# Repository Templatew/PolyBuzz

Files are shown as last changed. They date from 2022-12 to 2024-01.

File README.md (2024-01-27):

# Polybuzz

## Overview

Polybuzz is an innovative and interactive game box developed as a school project. It combines the excitement of arcade games with reflex testing exercises similar to those used in F1 pilot training. This versatile device offers multiple game modes and features a reward system that dispenses a treat after each game.

## Features

- **Multiple Game Modes:** Choose your game mode and play duration using a rotary encoder and an LCD screen.
- **Reward System:** Earn treats dispensed into a tray after each game.
- **Customizable Gameplay:** Adjust game settings for a personalized experience.

## Hardware Requirements

- Arduino Mega
- Rotary encoder
- LCD screen
- Various buttons and LEDs
- Power supply and other electrical components

## Installation

1. Assemble the hardware components based on the electrical schematic provided.
2. Upload the provided code to the Arduino Mega.

## How to Play

- Turn the rotary encoder to scroll through game modes.
- Press the encoder to select a mode and, if required, set the game duration.
- Engage in reflex-based games or other arcade-style challenges.
- Collect your reward after each game.

## Future Enhancements

- Addition of more game modes and difficulty levels.
- Integration of a score-saving feature using an SD card.

## Contributors

 - [CAZAUBON Lorenz](https://github.com/Templatew)
 - [MAUVOISIN Paul](https://github.com/Poblit0)

## Gallery
a4a9868a-1191-4484-97f6-19bce6ff1df2

https://github.com/Templatew/PolyBuzz/assets/96289463/65af232c-c642-4c31-b5ea-772e865da6ab

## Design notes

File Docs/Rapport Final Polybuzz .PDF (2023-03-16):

CAZAUBON Lorenz
MAUVOISIN Paul
G1 | PEIP2 | POLYBUZZ

### Sommaire

### - Présentation (page 2)

### - Planning (page 3)

### - Schéma électrique (page 4)

### - Diagramme code (page 5)

### - Coût (page 6)

### - Problèmes rencontrés (page 7)

### - Perspectives et conclusion (page 8)

### - Bibliographie (page 9)

1 2022-2023

### Présentation du Projet

Notre projet a pour but d'être une boîte pouvant à la fois servir de test de réflexe comme il est possible de retrouver dans les entraînements de pilotes de F1 et servir comme une boîte de jeu semblable à ceux que l’on peut avoir dans une salle d’arcade.

Ainsi il est possible de choisir grâce à un encodeur rotatif et un écran LCD le mode de jeu et le temps que nous souhaitons jouer.

A la fin de chaque partie, le système de récompense déverse dans le bac une friandise, et l’écran revient à son état initial et on peut relancer une nouvelle partie.

Modes de jeu :

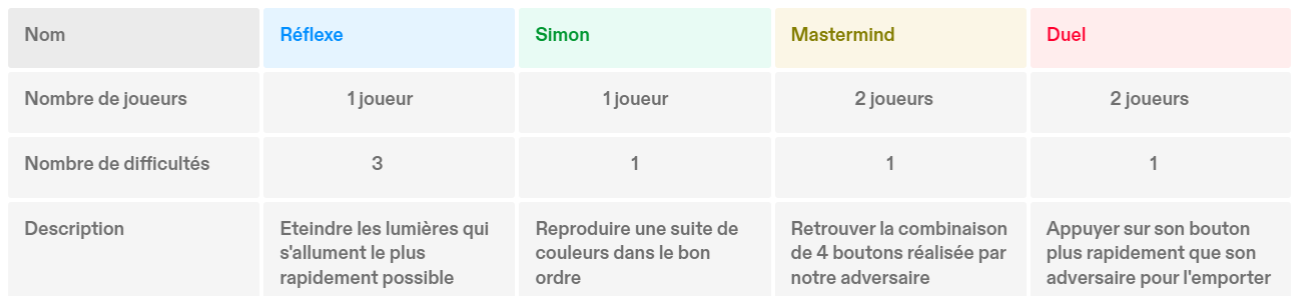
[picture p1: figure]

En pratique :

Comme indiqué sur l’écran lorsque le PolyBuzz est branché, il faut tourner l’encodeur rotatif. Ainsi défileront les modes de jeux disponibles, et il faudra cliquer sur l’encodeur rotatif pour le sélectionner.

Si le mode est un jeu réflexe il faudra tourner à nouveau l’encodeur et choisir le temps de jeu que vous souhaitez jouer, en cliquant une deuxième fois sur l’encodeur.
Sinon il suffira de d’actionner une deuxième fois l’encodeur pour déclencher le compte à rebours de 3 secondes avant le début de la partie.

2 2022-2023

### Planning

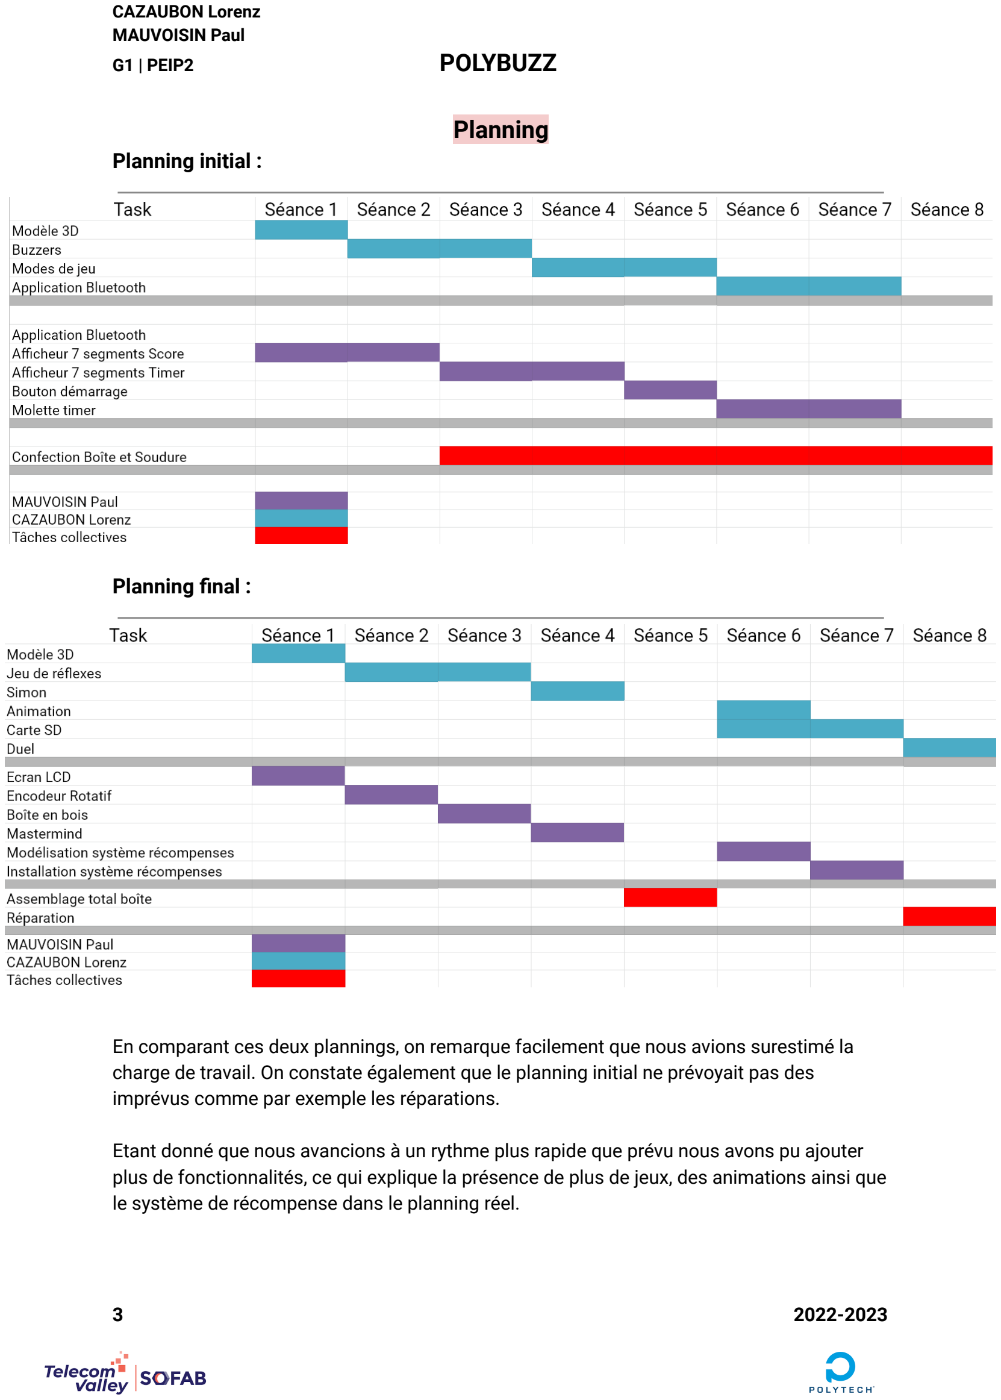
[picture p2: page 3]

Planning initial :

Planning final :

En comparant ces deux plannings, on remarque facilement que nous avions surestimé la charge de travail. On constate également que le planning initial ne prévoyait pas des imprévus comme par exemple les réparations.

Etant donné que nous avancions à un rythme plus rapide que prévu nous avons pu ajouter plus de fonctionnalités, ce qui explique la présence de plus de jeux, des animations ainsi que le système de récompense dans le planning réel.

3 2022-2023

### Schéma électrique

### Schéma électrique

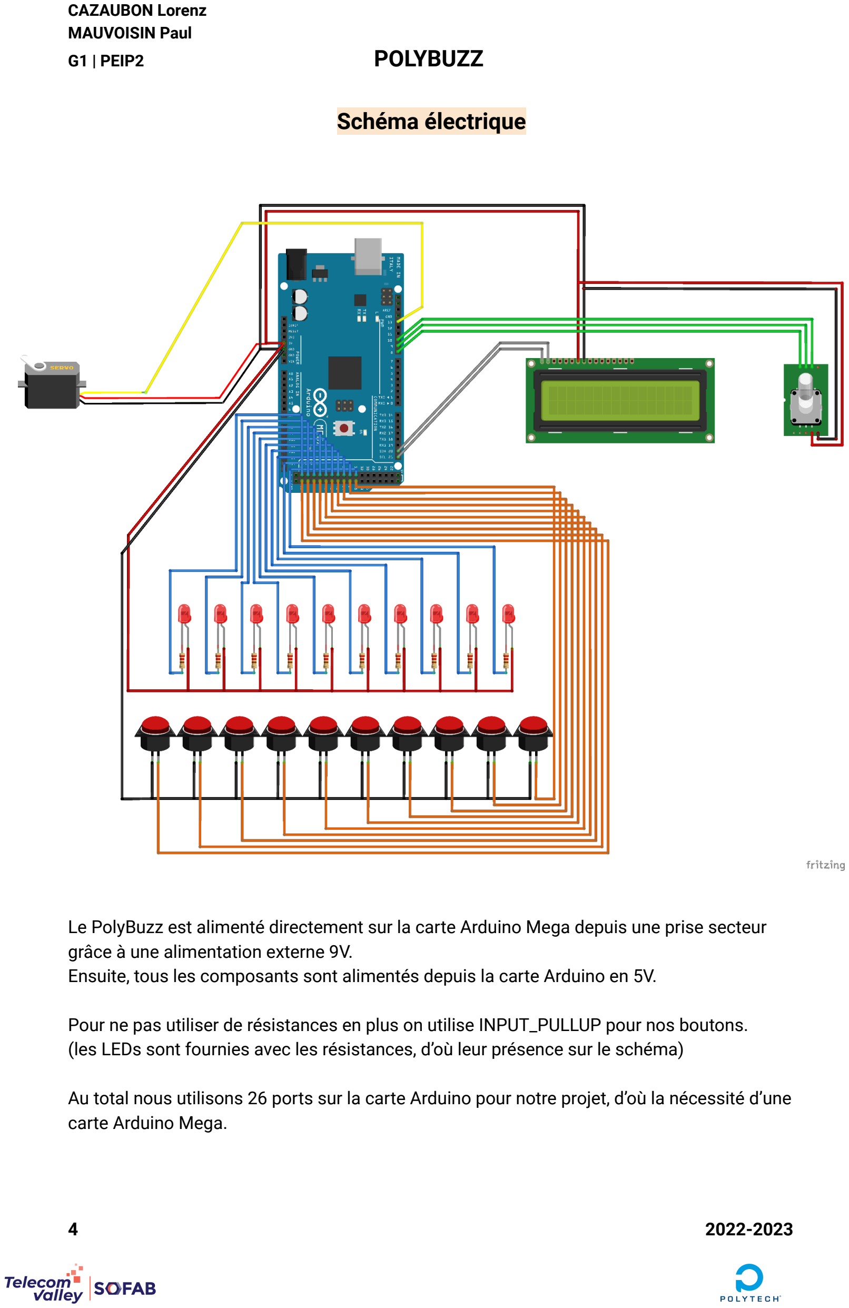
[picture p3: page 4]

Le PolyBuzz est alimenté directement sur la carte Arduino Mega depuis une prise secteur grâce à une alimentation externe 9V.
Ensuite, tous les composants sont alimentés depuis la carte Arduino en 5V.

Pour ne pas utiliser de résistances en plus on utilise INPUT_PULLUP pour nos boutons. (les LEDs sont fournies avec les résistances, d’où leur présence sur le schéma)

Au total nous utilisons 26 ports sur la carte Arduino pour notre projet, d’où la nécessité d’une carte Arduino Mega.

4 2022-2023

### Diagramme du code

Algorigramme du menu :

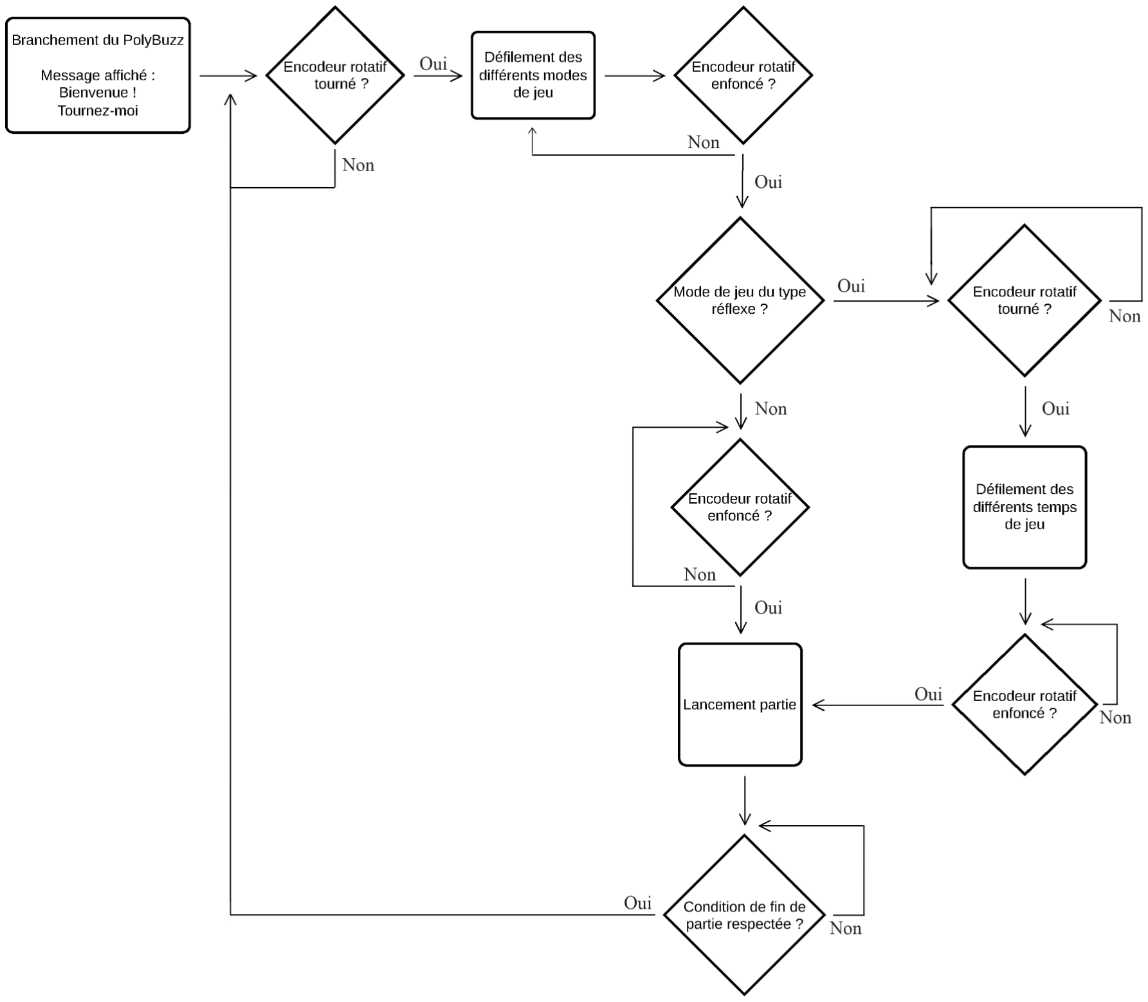
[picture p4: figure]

Les schémas algorithmiques des jeux ne sont pas représentés ici, par manque de place. Cependant si nécessaire nous pouvons les fournir.

5 2022-2023

### Coût

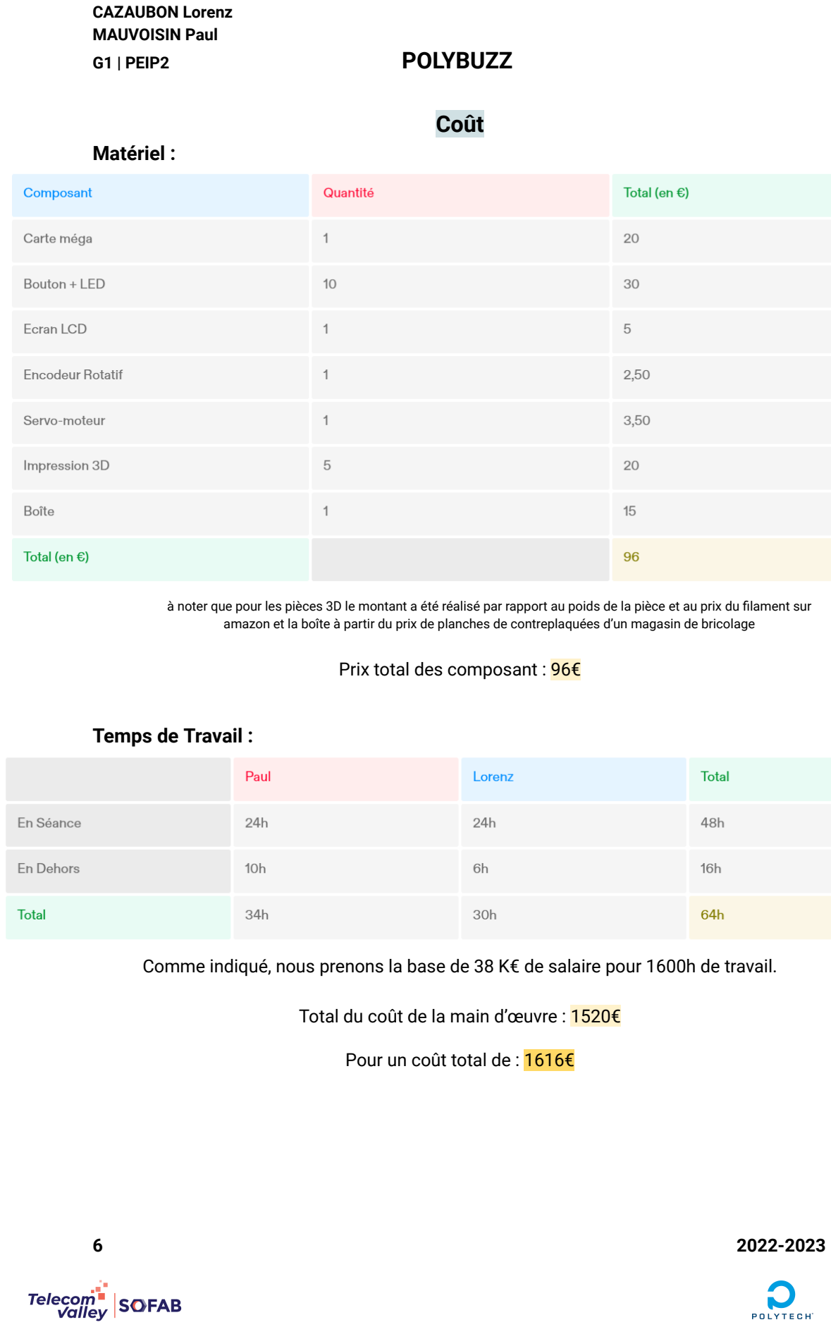
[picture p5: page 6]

Matériel :

à noter que pour les pièces 3D le montant a été réalisé par rapport au poids de la pièce et au prix du filament sur amazon et la boîte à partir du prix de planches de contreplaquées d’un magasin de bricolage

Prix total des composant : 96€

Temps de Travail :

Comme indiqué, nous prenons la base de 38 K€ de salaire pour 1600h de travail.

Total du coût de la main d’œuvre : 1520€

Pour un coût total de : 1616€

6 2022-2023

### Problèmes rencontrés

Lors de la réalisation de ce projet nous avons été confrontés à quelques problèmes que nous avons dû résoudre afin de poursuivre l’avancement de notre PolyBuzz.

- Tout d’abord dans la partie code, nous avons dû apprendre à utiliser le plus possible des intervalles de temps (grâce à la fonction millis() ) plutôt que des delay() qui bloquent toutes les fonctionnalités lors de leur exécution.
- Nous avons tous les deux travaillés de notre côté au début du projet, réalisant des morceaux de codes au fur et à mesure.
Cependant cela a posé problème lors de la fusion des codes, en effet beaucoup de variables portaient le même nom, des méthodes étaient incompatibles entre elles,.. En résumé, il y avait beaucoup à corriger pour que le code final soit entièrement fonctionnel et sans bug majeur.
- La quantité de câbles étant importantes ce fut difficile de réaliser le branchement final, pour ne rien arranger nous avons dû changer de carte Arduino à deux reprises suite à des problèmes sur ces dernières. Cet ensemble de câble a donc été notre bête noire lors de ce projet. Cependant ces quelques astuces nous ont simplifiées la tâche:
- Numéroter les boutons de 1 à 10.
- Prendre une photo très détaillée des branchements.
- Utiliser un maximum de nappes de fils pour regrouper les composants.
- Avoir une boîte suffisamment solide pour que le joueur puisse jouer convenablement. Nous avons donc réalisé une boîte en bois (épaisseur de: 5mm), renforcée grâce à des équerres en plastique un peu partout à l’intérieur. En effet, il est complexe de trouver des équerres ainsi que des vis adaptées au bois de 5mm dans un but esthétique où aucune vis ne dépasserait de la boîte. Il a fallu donc utiliser deux rondelles en métal pour chaque vis afin de les réhausser et qu’elles ne passent pas au travers du bois.

Ainsi, il est possible de constater qu’aucun obstacle insurmontable ne s’est confronté à nous, ce qui marque tout de même un point négatif étant donné que faire face à l’échec et apprendre à le surmonter est une qualité essentielle dans notre apprentissage.

7 2022-2023

### Perspectives

&

### Conclusion

Notre projet est fonctionnel….

Grâce au cours d’électronique avec arduino, nous avons pu réaliser notre projet de jeu, dans lequel le joueur doit appuyer sur des boutons qui s’allument de façon aléatoire pour gagner des points dans un temps qu’il aura choisi.
Nous sommes même allés plus loin que ce qui était prévu, en réalisant 4 jeux au total ainsi qu’un système de récompenses, cependant toute la partie bluetooth a été abandonnée au profit d’une sauvegarde des meilleurs scores sur une carte SD (Fonctionnalité non terminée).

….mais pourrait être amélioré, si nous avions plus de temps voici quelques points que nous aimerions perfectionner.

- Tout d’abord nous pourrions réaliser plus de modes de jeux, comme un jeu pour 3 joueurs ou encore 4, mais aussi plus de difficulté afin d’offrir plus de liberté à l’utilisateur/joueur.
- Souder chaque câble afin d’éviter tous les problèmes de déconnexions.
- Rendre fonctionnel la sauvegarde des meilleurs scores sur carte SD.
- Alimenter les LEDs en 12V au lieu des 5V actuels, pour une meilleure visibilité. (Les LEDs sont conçues pour du 5V)
- Corriger les quelques problèmes d’impression 3D, la pente ne permet pas toujours aux “friandises” de tomber pour que le joueur puisse les attraper.

En conclusion, ce projet nous a permis de mettre en pratique des connaissances et des idées que nous avions. Nous avons appris à résoudre des problèmes pas toujours évidents étant donné notre manque d’expérience, mais avec de la volonté et de l’entraide nous avons pu transposer nos idées dans la réalité.
Certes notre projet n’est pas des plus complexes, cependant ce dernier est fonctionnel, ludique et peu coûteux (Hors main d'œuvre). Ainsi il nous a offert des beaux moments comme par exemple à la journée portes ouvertes lorsque Mr Masson l’a essayé !

8 2022-2023

### Bibliographie

Pour l’utilisation de l’écran LCD : https://www.gotronic.fr/pj2-sbc-lcd16x2-fr-1441.pdf

Pour l’utilisation de l’encodeur rotatif : https://www.aranacorp.com/fr/utilisation-dun-encodeur-rotatif-avec-arduino/

Pour l’utilisation de la fonction millis() : https://www.aranacorp.com/fr/utilisation-de-la-fonction-millis-de-lide-arduino/

Nous avons également eu recours à des sites et des logiciels tels que :

Maker Case pour la confection de la boîte : https://fr.makercase.com/#/

InkScape pour les retouches avec la découpe laser de la boîte.

OnShape pour modéliser les pièces en 3D du système de récompense.

9 2022-2023

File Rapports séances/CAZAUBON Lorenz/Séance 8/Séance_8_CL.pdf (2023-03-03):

CAZAUBON | Polybuzz
Lorenz
G1 | PEIP 2
Séance 8

Lors de cette séance j’ai codé le mode de jeu “Duel”.
Ce jeu consiste à allumer deux leds (Bouton et LED 1 pour le joueur 1, pour le joueur 2 le bouton et LED 4) quand un intervalle de temps aléatoire s’est écoulé. Le premier à appuyer sur le bouton lorsque celui-ci s’allume gagne alors un point. Cependant si l’un des joueurs appuie sur le bouton en avance il offre le point à son adversaire. Lorsque l’un des joueurs atteint le score de 3 points, il remporte la victoire.

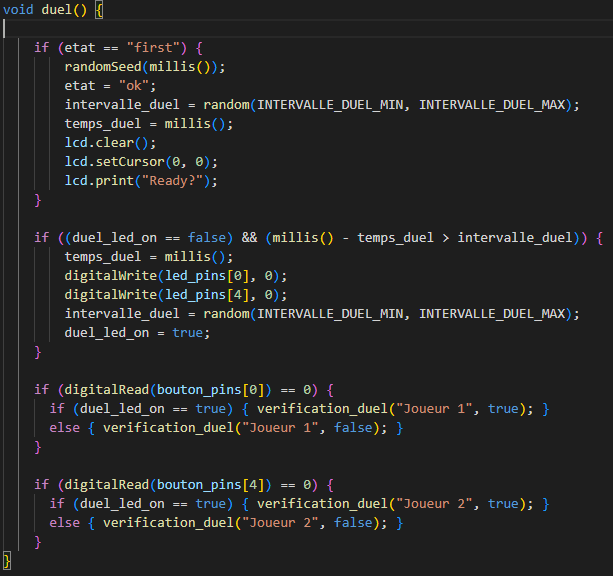
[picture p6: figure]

La fonction verification_duel nous permet d’afficher sur l’écran, qui a gagné et d’attribuer les points.

1 | 2022-2023

CAZAUBON | Polybuzz
Lorenz
G1 | PEIP 2

Malheureusement je n’ai pas eu le temps de rendre le système de sauvegarde des meilleurs scores sur la carte sd fonctionnel. Cet aspect sera donc à terminer si jamais nous décidons de refaire ce projet. En attendant que cette fonctionnalité soit opérationnel, voici le meilleur score en réflexe hard 30s: 53

Lors de cette séance nous avons donc réalisé le montage final qui ne devrait pas changer avant la présentation, celui-ci est équivalent à l’image:

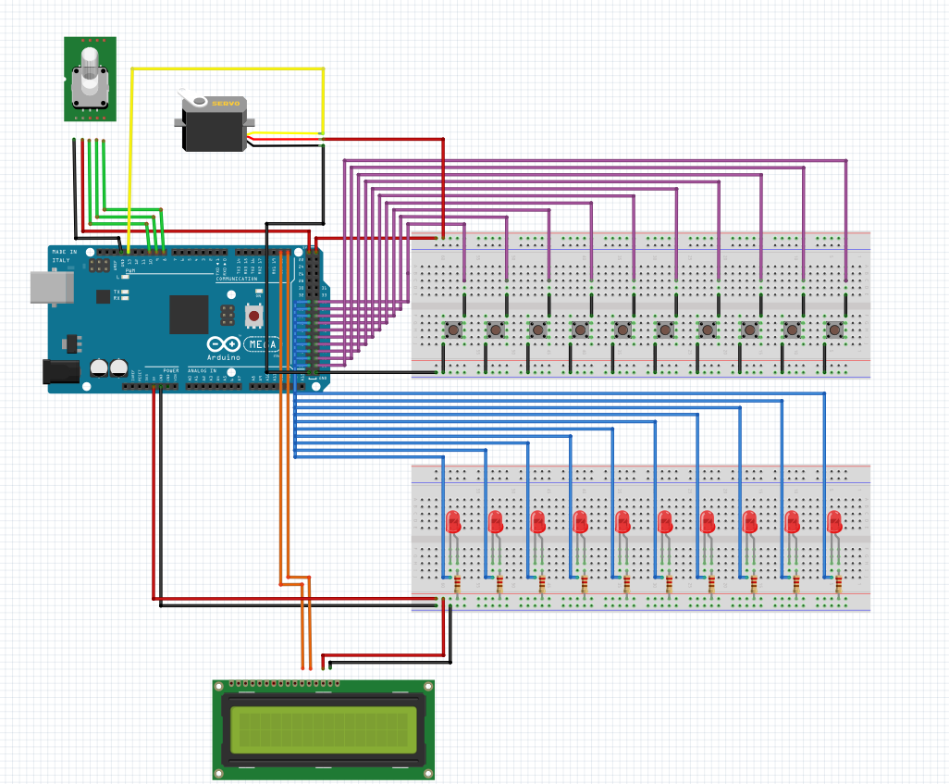
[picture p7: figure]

Nous avons donc utilisé 10 LEDs, 10 Interrupteurs, 10 Résistances, 1 Écran LCD, 1 Encodeur Rotatif, 1 Servomoteur, 1 Carte Arduino Mega.

2 | 2022-2023

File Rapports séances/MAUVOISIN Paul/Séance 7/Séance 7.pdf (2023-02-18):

En début de semaine, je suis allé faire imprimer en 3D la version final des pièces pour le système de récompense.

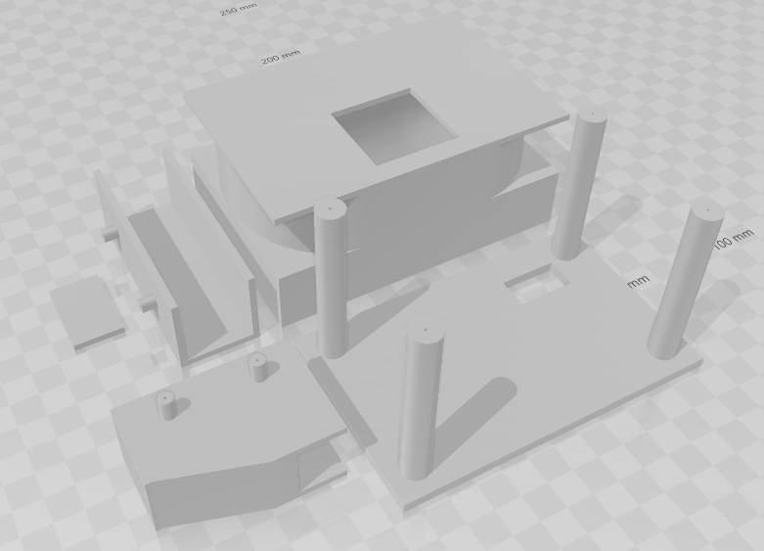
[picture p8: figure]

J’ai ensuite pu assembler le système, en commençant par placer le servo-moteur pour aligner les autres éléments en fonction de lui car il est la pièce maîtresse du système.
Le trou était légèrement mal mesuré mais à la lime ce n’était pas un problème.

Pour ce qui concerne les entretoises que j’avais incrusté dans les pièces elles sont parfaitement placées.
Seul remarque il aurait fallut 3 pieds au récipient pour qu’il soit un trépieds, ce qui aurait faciliter sa mise en place.

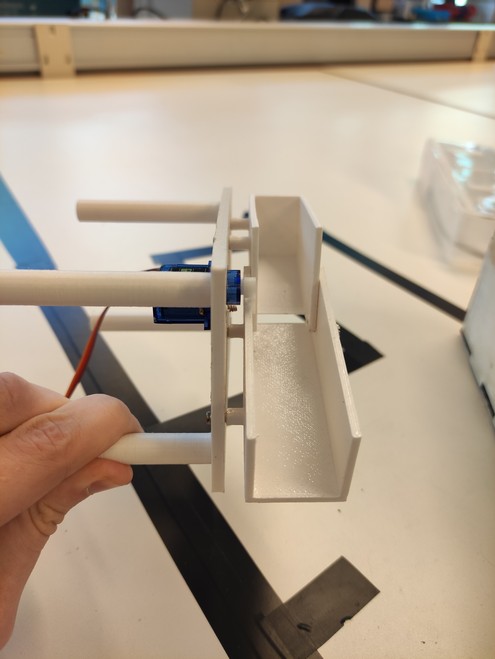
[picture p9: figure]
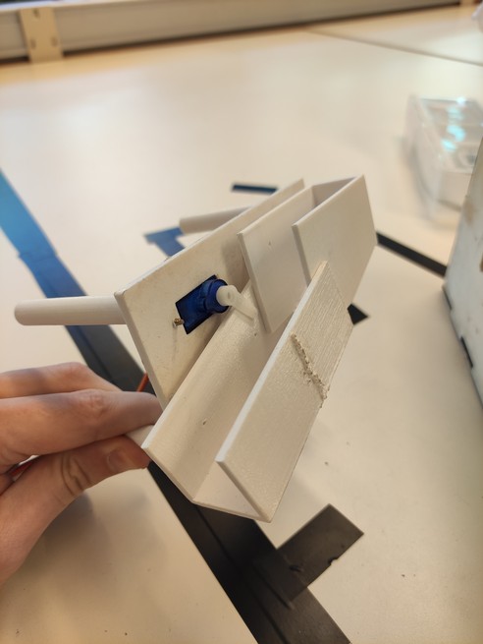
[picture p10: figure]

Également, j’avais déjà pensé à faire un trou pour l’équerre en plastique mais le trou à l’arrière du bac était trop petit mais à la lime ce n’était toujours pas un problème majeur.

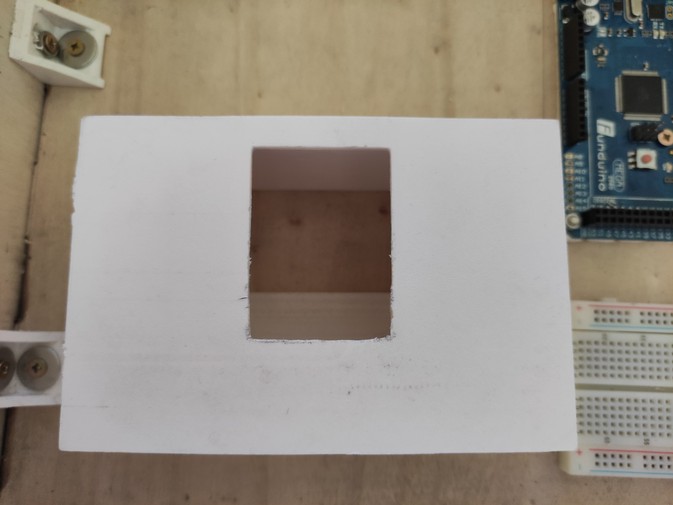
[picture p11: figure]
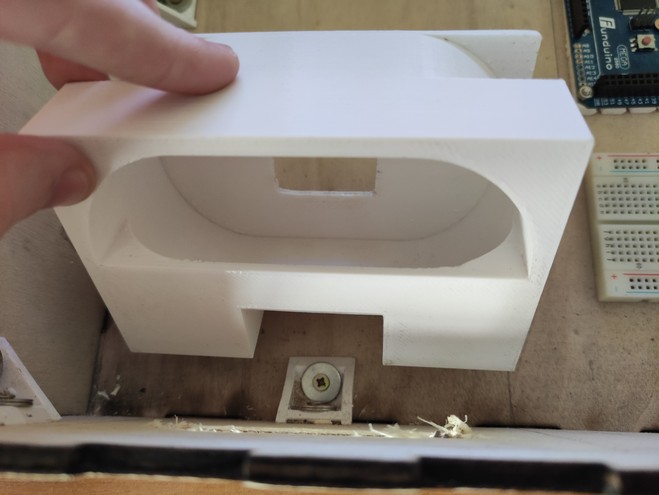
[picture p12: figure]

Par conséquent, il ne reste qu’à coller la trappe au servomoteur, stabiliser avec des vis le bac et creuser un trou dans la boîte pour passer les doigts (je dois encore l’agrandir)

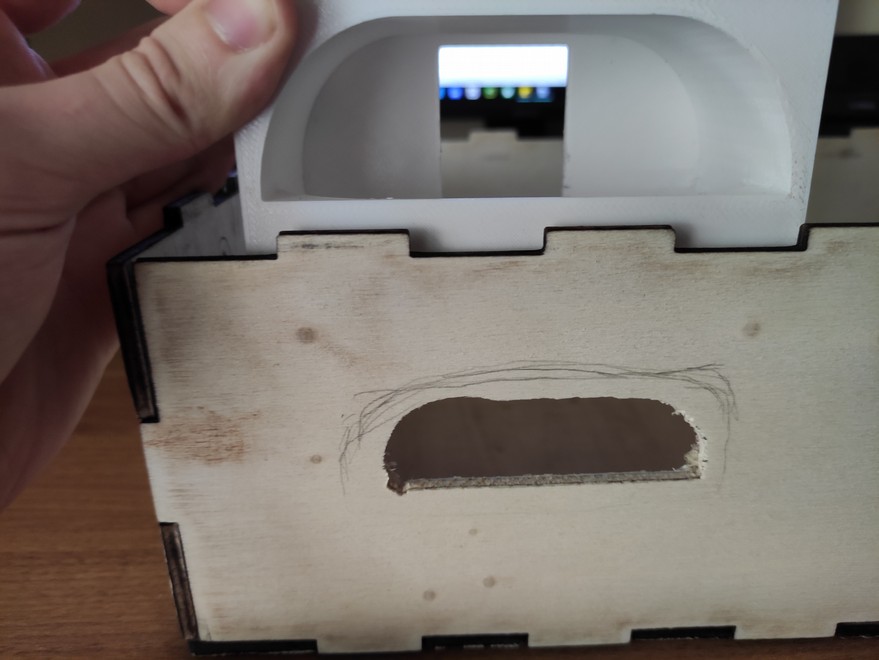
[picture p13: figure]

Un rendu final sera comme ceci.

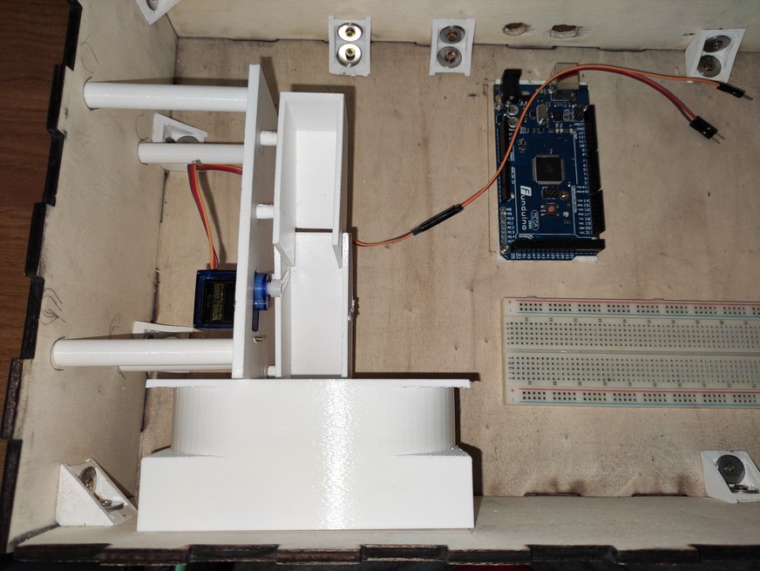
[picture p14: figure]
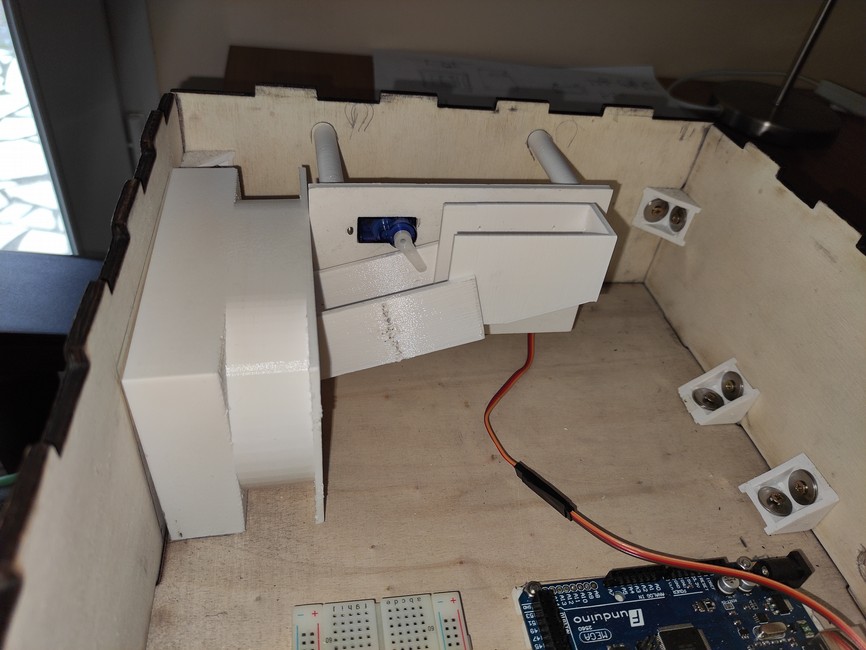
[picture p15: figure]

A noter que deux LED (une rouge et une bleue) ne s’allument plus, mais leur bouton associé fonctionne toujours, je vais donc régler ce problème durant les vacances car je n’ai pas emmené les cosses aujourd’hui.

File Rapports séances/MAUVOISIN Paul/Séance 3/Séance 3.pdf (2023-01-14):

Aujourd’hui je vais effectuer la boîte de support en bois.

Pour cela je vais utiliser le site Maker Case, afin d’obtenir les fichiers au bon format pour la découpeuse laser.

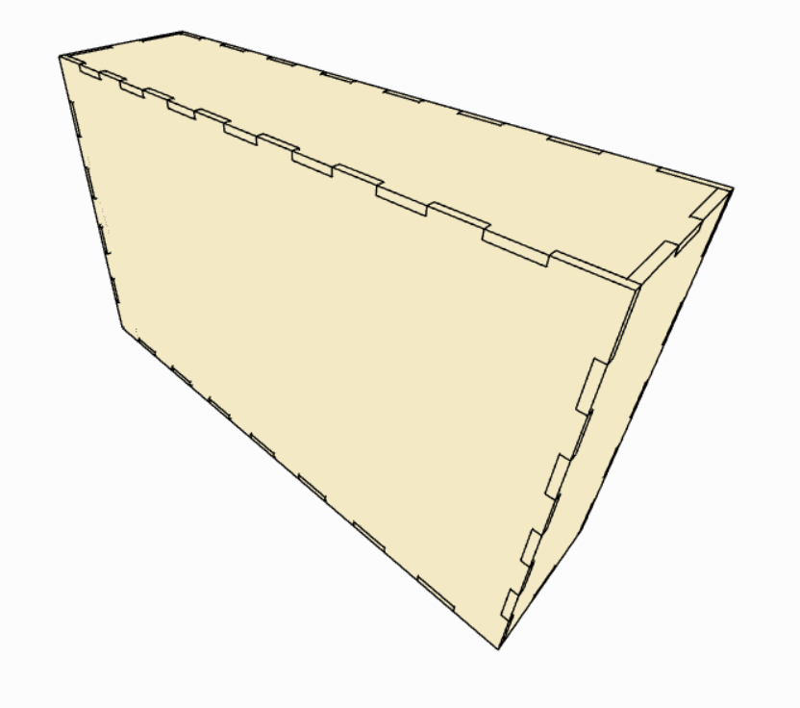
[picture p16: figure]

Les dimensions sont celles que Lorenz a défini dans son rapport de séance 1, à l’exception de la hauteur que l’on peut réduire.
Finalement, les dimensions sont donc : 420-260-110 mm et 5mm d’épaisseur

Cependant nous avons également besoin de faire des trous dans la partie supérieur de la boîte. On a besoin de trop pour :
les 10 boutons
l’écran LCD
l’encodeur rotatif
Pour cela je vais utiliser, le logiciel InkScape.

Les boutons sont des trous de 25mm de diamètre. L’écran LCD a un trou de 72mm par 25mm. L’encodeur rotatif a un trou de 8mm par 8mm.

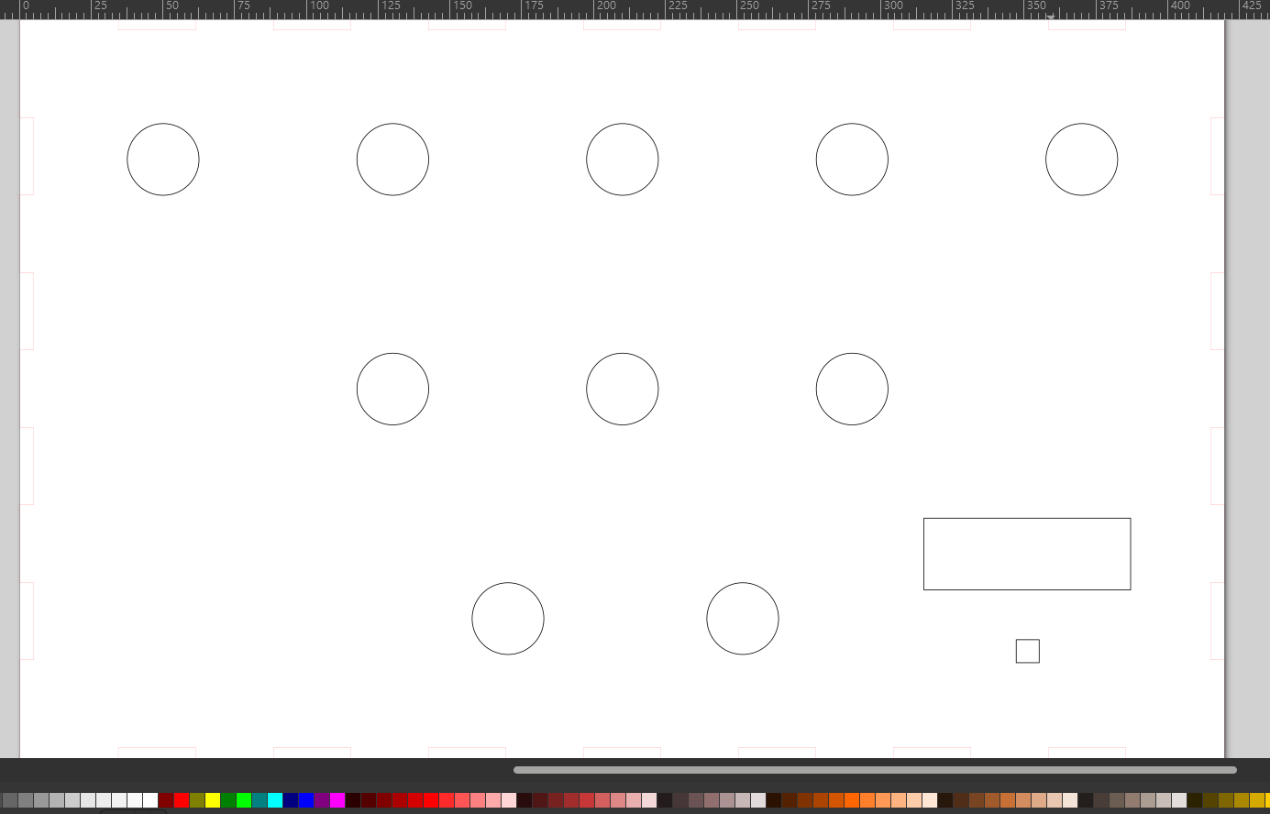
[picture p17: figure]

Maintenant, il faut attendre la semaine prochaine pour avoir la boîte en pièces séparées.

Pour le reste du cours, je vais retourner au code.
Je vais mettre des commentaires pour qu’il soit plus compréhensible par mon binôme et ceux qui souhaiteraient y avoir accès.

Pendant le temps qu’il me reste je vais encore tenter de résoudre le problème lié au Timer.

Des solutions ont été trouvé tandis que des problèmes ont été découverts.

A priori, il ne resterait qu’un problème qui ne me semble pas très compliqué mais je ne parviens quand même pas à le résoudre : pour la durée du jeu qui s’écoule nous utilisons la fonction millis(). Le problème est que cette fonction démarre au début du programme et donc le temps passé à choisir son mode de jeu et son temps sont comptabilisés dans la durée de la partie.

J’ai découvert que millis() ne pouvait pas être remise à 0, et le conseil donné est de calculer l’écart entre les deux périodes mais malgré mes tentatives, aucunes n’a pour l’instant fonctionné.

Je vais résoudre ce problème majeur car sinon la présentation du projet de la semaine prochaine risque d’être compliqué.

Le lendemain : c’est bon le code est fonctionnel, grâce à un commentaire d’une personne qui avait un problème, j’ai trouvé comment l’adapter au mien, ce qui donne :

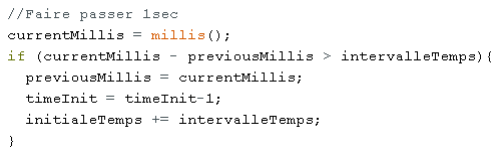
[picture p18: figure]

Lien du site où se trouvait le commentaire (lien cliquable dans le fichier « lien ») : https://www.aranacorp.com/fr/utilisation-de-la-fonction-millis-de-lide-arduino/

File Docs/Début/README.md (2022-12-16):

<body>
    <h1>PolyBuzz | Cahier des Charges</h1>
    
Projet Arduino – 2022/2023
<br>De CAZAUBON Lorenz et MAUVOISIN Paul - Groupe 1<br>

<h2>Idée principale :</h2>
    <p>Créer un projet à mi-chemin entre jeu et test de réflexe</p>

<h2>Origine de l’inspiration :</h2>
    <p>Reproduire un test de réflexe comme ceux que l'on peut voir dans les entraînements de Formule 1.
    <br>L'objectif de ce test est d'éteindre le plus de lumières qui s’allument en appuyant dessus.<br>
</p>

<h2>Apparence :</h2>
    <ul>
        <li>Physique : Le jeu est une boîte sur laquelle est disposée 10 buzzers. Sur cette même surface est apparent deux afficheurs, l'un pour le score du joueur, l'autre pour le temps restant. Et également un bouton pour démarrer la partie</li>
        <li>Virtuel : Une interface sur téléphone connectée par bluetooth donne des informations complémentaires sur la partie : score, pourcentage de précision, nombre d'erreurs (buzzers éteints appuyés), classement, etc</li>
    </ul>

<h2>Plusieurs modes de jeu :</h2>
    <ul>
        <li>Mode facile : Les lumières ne s’éteignent que lorsqu’on a appuyé dessus</li>
        <li>Mode normal : Les lumières s’éteignent également au bout d’un certain temps fixe</li>
    </ul>

<h2>Matériel :</h2>
    <ul>
        <li>1 boîte (à terme en bois)</li>
        <li>10 buzzers</li>
        <li>1 module bluetooth</li>
        <li>A compléter..</li>
    </ul>

</body>

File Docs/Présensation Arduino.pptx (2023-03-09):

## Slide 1

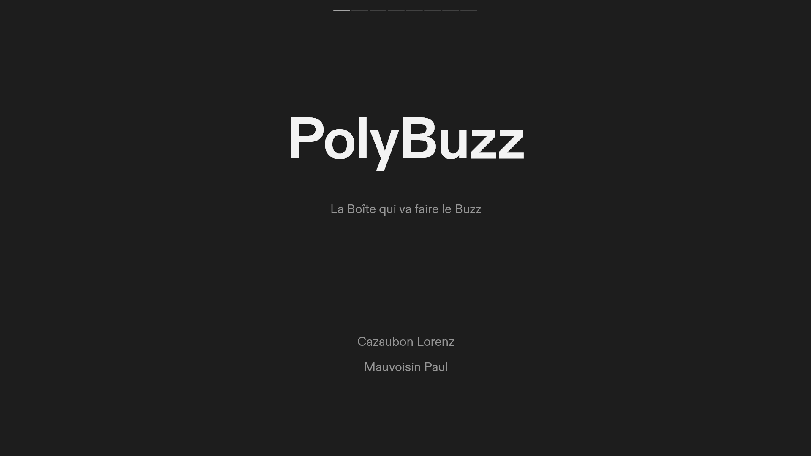
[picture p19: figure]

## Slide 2

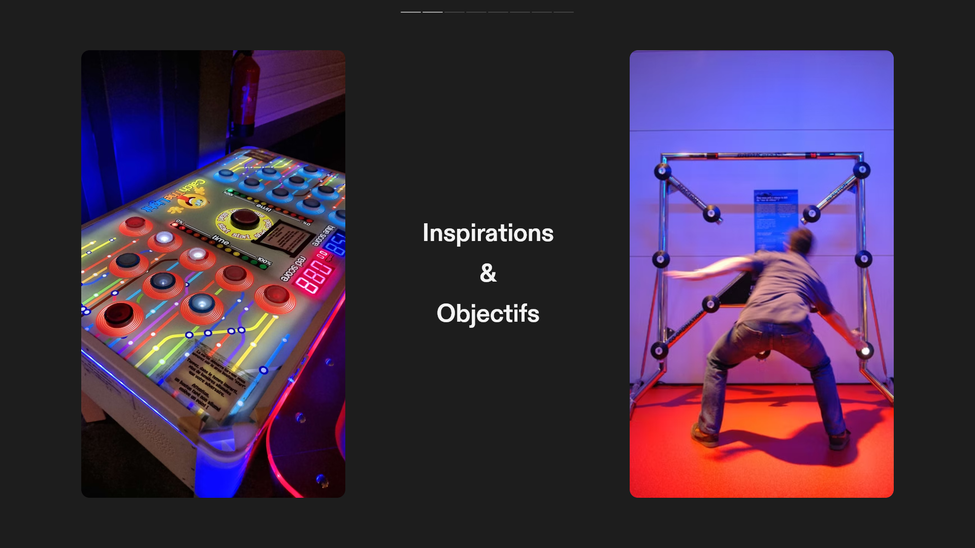
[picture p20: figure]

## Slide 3

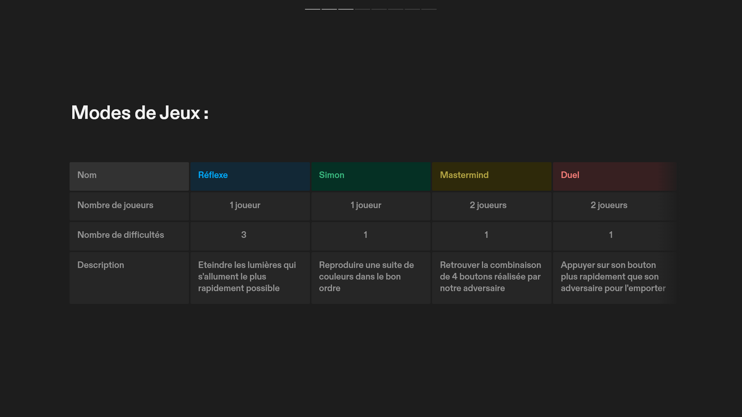
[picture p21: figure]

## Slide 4

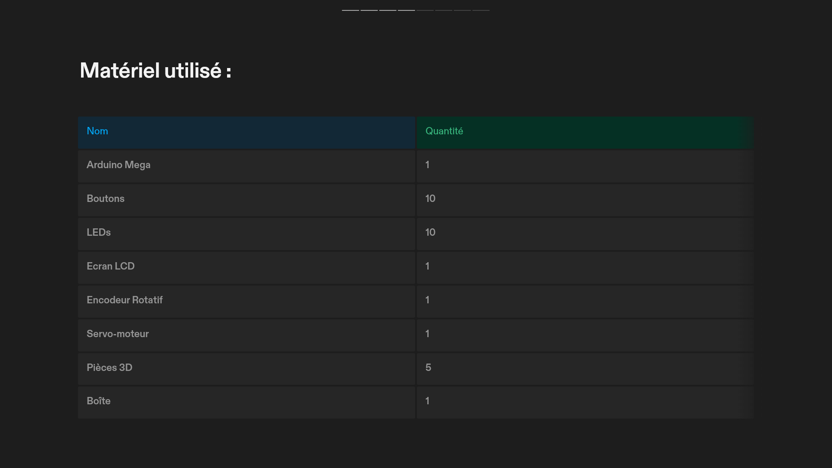
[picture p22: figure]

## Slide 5

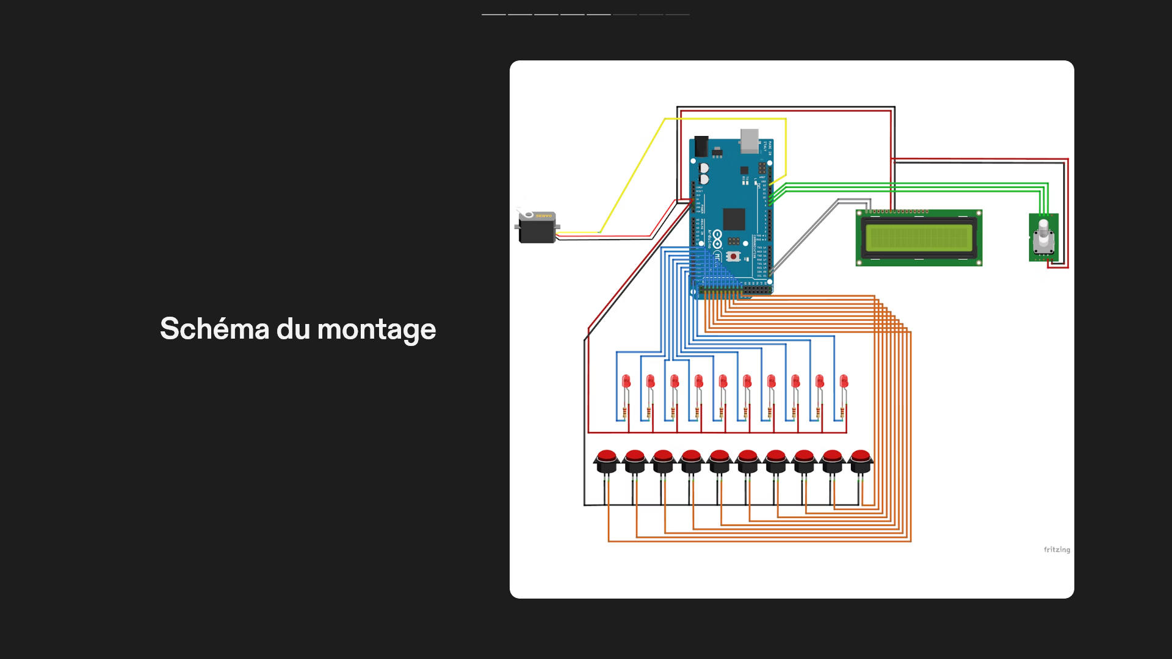
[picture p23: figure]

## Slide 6

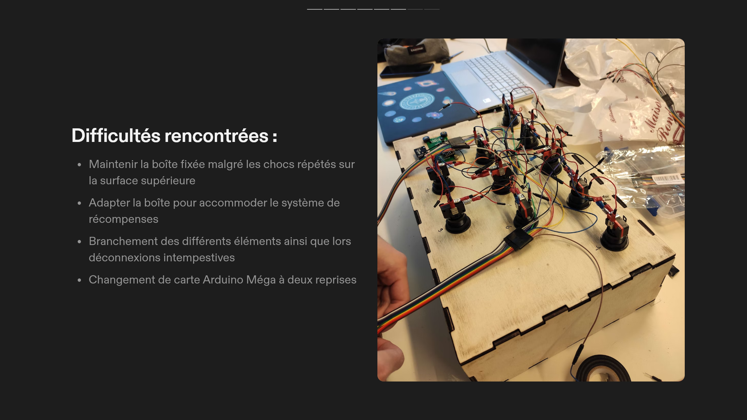
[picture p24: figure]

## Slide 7


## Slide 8


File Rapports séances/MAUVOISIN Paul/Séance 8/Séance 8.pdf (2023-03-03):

Aujourd'hui est donc la dernière séance avant la présentation orale.

L'objectif est de :
- réparer les 2 LED qui ne s'allument plus
- implémenter le code pour les récompenses
- essayer de rendre le code plus « propre » avec le temps qu’il me restera

La réparation des LED fut fastidieuse avec notre amas de fils, cependant grâce à notre câble managment sommaire et rudimentaire mais néanmoins efficace j’ai pu réduire les possibilités d’emplacement des deux problèmes.
Finalement, j’ai pu trouver l’origine exacte des dysfonctionnements qui étaient deux fils qui étaient chacun déconnectés dans le scotch qui les maintenaient et qui du coup était caché par celui-ci.
Le PolyBuzz refonctionne à nouveau parfaitement !

Le code pour les récompenses est très basique, il s’agit simplement de trouver le bon angle et la bonne vitesse de rotation du servo-moteur.
Ainsi de manière empirique, j’ai constaté qu’une ouverture de 60° de 500ms est suffisante.


(je ne dépose pas le code dans cette Séance car je l’ai implémenter directement dans le code général, de plus celui-ci est plus que classique)

Cependant, la pente de mon module de récompenses n’est pas assez abrupte, mais il n’est pas possible de l’augmenter à cause la limite en hauteur dont je dispose, il sera donc judicieux de trouver un substitue aux actuelles récompenses même si cela ne représente un problème ni urgent ni vital.

Pour ce qui concerne le 3ème point je ne vais pas relever toutes les petits modifications que j’ai réalisé, pour être succinct j’ai principalement corrigé une faute d’orthographe qui représente une erreur très préjudiciable qui apparaissait sur l’écran LCD ainsi que remplacé certains éléments que non optimaux par des boucles ce qui est préférable.


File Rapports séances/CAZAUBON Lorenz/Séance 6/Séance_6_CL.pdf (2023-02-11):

CAZAUBON | Polybuzz
Lorenz
G1 | PEIP 2

Séance 6:

Dans cette séance nous avons dû changer de carte arduino, étant donné que le port micro usb de cette dernière est dessoudé. La carte étant fixée par quelques vis, cette opération a heureusement été rapide.

Par la suite, j'ai pu créer le code pour les animations de boutons lors du choix du mode de jeu et le tester (Voir vidéo).
Le code utilise une fonction animation pour l’éclairage des leds, cette fonction ne s’exécute seulement si (bool) animation_on == true, ainsi cet ajout ne gêne pas l'exécution normal du code, une version précédente qui utilisait des delays avait pour effet de rendre le jeu inutilisable (c’était prévisible étant donné que lors d’un delay la carte “attend”).

De plus je me suis penché sur la question de comment rendre le jeu entièrement autonome, c’est-à-dire d’intégrer directement à notre projet un moyen de stocker les meilleurs scores des joueurs.
La solution est d’utiliser un module pour carte sd (Voir photo).

Grâce à ce dernier plus besoin d’un ordinateur pour sauvegarder
les données.


Pour le moment ce système n’est pas encore fonctionnel mais d’ici
la prochaine séance ça devrait être le cas.

Enfin il reste toujours quelques bugs à corriger notamment certains liées au changement de carte, apparemment cette carte a quelques difficultés pour recevoir les données lors d’un téléversement avec arduino, à voir par la suite comment cela se déroule.

1 | 2022-2023

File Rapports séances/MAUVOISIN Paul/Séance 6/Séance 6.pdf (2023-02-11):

Le projet initial est en somme terminé, il nous faut donc trouver des améliorations.

Selon mon binôme, il est préférable de finaliser ce que nous avons déjà, c’est-à-dire :
- réaliser des motifs lumineux durant la sélection du mode de jeu pour occuper la vue du joueur
- finaliser les modes de jeu Normal, Hard et Duel
- créer un HighScore pour rendre le projet autonome

Étant donné que l’on ne peut pas travailler sur la boîte en même temps je vais tenter de réaliser quelque chose à part.

L’objectif est de donner des récompenses si le joueur atteint un certain score dans le mode de jeu Réflexe.

Pour se faire je vais utiliser un servomoteur qui va verser des TicTac (ou autre mais cela me semble être une bonne solution en guise de récompense, et en terme de poids)

Le servomoteur aura dans la continuité la partie qui servira à retenir le récipient de récompense qui amène ensuite sur une petite gouttière, et possédera deux positions : haute et basse.

La position haute servira à bloquer le contenant de lequel se trouve des TicTac et la position basse permettra de les faire glisser dans la gouttière.
Il faudra également faire un trou dans la boîte de petite taille pour que 2 ou 3 TicTac puissent passer.


Il serait intéressant de réaliser cette partie à l’imprimante 3D pour découvrir son processus, je vais donc designer les pièces manquantes au système.

Au total, il faudra :
- le récipient (partie en carton sur les photos supérieurs)
- la trappe qui ferme le récipient
- la gouttière
- le bac de récupération
Récipient | Gouttière


Trappe (en gris)


Bac de récupération


J’ai réalisé ces modèles 3D sur OnShape, puis exportés au format STL, il ne reste plus qu’à faire l’impression.

Également, je dépose dans le répertoire un petit bout de code qui est ma découverte du code pour un servomoteur, mais rien de très intéressant.

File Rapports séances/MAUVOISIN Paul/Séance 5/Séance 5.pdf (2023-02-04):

Aujourd’hui est la veille de la JPO, nous allons donc nous hâter pour rendre le PolyBuzz véritablement fonctionnel.

Nous devons donc :
- fusionner les codes
- brancher tous les fils aux 10 boutons, à l’écran et à l’encodeur de manière définitive


Nous nous sommes mutuellement entraider pour tout fixer avec un bout de scotch sur chaque liaison pour être sûre que les connexions ne se rompent pas, par conséquent le travail de Lorenz et le mien se sont entrecroisés et ne sont pas différents.

Également, nous avons raccordé 2 nappes de fils entre elles pour que chaque fil puisse atteindre sa destination tout en nous laissant un peu de mou (environ 10cm d’ouverture de boîte) pour ouvrir la boîte et brancher les fils.
Nous avons aussi utiliser de la pâte à fixe pour du câble managent afin de dissocier les fils pour les LED et les fils pour les boutons, ainsi que pour l’alimentation.


En fin de compte nous obtenons ceci :

Cela nous a pris l’entièreté de la séance (ainsi que la fusion du code qu’à fais Lorenz), et nous pourrons présenter demain notre projet à la JPO avec 3 modes de jeu.

Remerciement spécial à notre premier jouer.

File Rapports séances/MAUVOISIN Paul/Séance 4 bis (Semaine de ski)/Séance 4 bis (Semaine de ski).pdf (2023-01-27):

Ceci est un rapport qui résume l'avancement du projet pendant la semain de ski qui a lieu entre la Séance 4 et la Séance 5.

Ce rapport à lieu car je voulais que le projet soit le plus présentable possible pour la Journée Portes Ouvertes qui se déroule le samedi 4 février.

Lors de la Séance 5 qui aura lieu la veille de la JPO.

Donc, place au résumé de l'avancement.

Tout d'abord le mode de jeu Mastermind est terminé, ce qui octroie à notre boîte de jeu, un jeu supplémentaire. Les étapes étant longues je ne mes qu'une photo du montage réalisé avec 4 boutons.


Pour rappel notre adaptation du Mastermind est fait comme ceci :

Le jeu est décomposée en 2 phases.

Lors de la première phase, un joueur A appuie sur 4 des 10 boutons qui s’allumeront, présents sur la boîte et fait valider cette combinaison, que l’on va appeler ‘code’, en appuyant sur l’encodeur rotatif.

Lors de la deuxième, un joueur B va tenter une combinaison de 4 boutons qui s’allumeront et la faire valider à l’encodeur rotatif, ainsi l’écran LCD lui répondra le nombre de boutons allumées en accord avec le ‘code’ du joueur A.

Ainsi le joueur B aura x nombre de tentative pour retrouver le ‘code’ qui a été créé par le joueur A.

Par conséquent, dans notre adaptation : il n’y a pas de notion d’ordre, c’est-à-dire que le code Rouge Vert Bleu Blanc sera le même code que Bleu Blanc Rouge Vert.La raison de cette simplification est due au fait que les codes testés par le joueur B ne lui sont pas présentés sous les yeux et donc pour faciliter l’effort de mémoire il n’y a pas de notion d’ordre

Ensuite, j’ai poncé au papier de verre le planche supérieur pour que l’écran ne sois plus incliné à cause de son excroissance blanche.


Aussi, j’ai collé 4 planches de la boîte pour consolider le tout, et trouer à la perceuse la planche arrière de la boîte pour laisser passer le câble micro USB pour mettre à jour la carte arduino ainsi que l’alimentation.

J'ai également eu l'idée d'un autre jeu : le Duel

Le jeu est simple, c'est un face à face de rapidité entre deux joueurs.
Les deux joueurs ont chacun un bouton assigné.

Au bout d'un certain temps, les deux boutons vont s'allumer et le premier qui appuie sur le sien gagne un point.

Le premier à 3 points gagne.
Si un joueur tente d'appuyer avant que son bouton ne s'allume, il perd un point !

Egalement, j'ai pu tenté de fusionner les codes.
Cela fonctionne correctement malgré le fait que j'ai du renommer certaines variables ce qui est tout à fait normal.

Cependant, étant novice dans le code, j'ai beaucoup de variable qui m'aide à régler des problèmes, je tenterai par la suite d'alléger mon code mais l'objectif pour le samedi 4 février est la fonctionnalité.

Donc pour la Séance 5 nous allons tout assembler et faire les tests à 10 boutons.

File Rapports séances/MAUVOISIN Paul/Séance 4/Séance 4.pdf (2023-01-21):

Aujourd'hui nous avons pu récupérer la boîte qui a été réalisée à la découpeuse laser.

Nous avons donc pu essayer si les dimensions étaient correctes :
- les boutons rentrent bien dans leur emplacement, donc pas de problème ici.
- l’écran LCD est légèrement incliné à cause d’une légère encoche blanche, car en mesurant, l’écran se place parfaitement si l’épaisseur de la planche est de 4mm, mais pour une raison de solidité qui est primordiale nous avons privilégié de prendre l’épaisseur maximale qui est de 5mm, quitte à gratter le bois afin que cette petite encoche rentre bien, donc les dimensions sont conformes.


(cela ne se voit pas très bien sur la photo mais l’inclinaison est flagrante dans la réalité)

- l’encodeur rotatif n’a pas un trou à la bonne dimension, le but était que la base métallique de l’encodeur rentre dans le carré, mais heureusement l’embout dépasse largement et donc nous pourrons conserver ce léger défaut.


Par conséquent tout est en ordre il suffit simplement de gratter légèrement pour ramener l’écran droit.
Également, je compte, durant cette semaine de séparation entre les semestres, poncer au papier de verre les planches afin de retirer les parties brûlées.

Erreur dont nous venons de nous apercevoir ! Nous n’avons créer de trou afin que la carte dépasse de la boîte et puisse être connectée par USB et être alimentée.
Je tenterai dans la semaine de vacances de résoudre ce problème par moi-même car le FabLab est pris d’assaut en ce dernier vendredi avant la semaine de ski.

Pour le reste de la séance je vais m’atteler au code d’un nouveau mode de jeu dont j’ai eu l’idée dernièrement, il s’agit d’un équivalent de Mastermind.

Fonctionnement :
Le jeu est décomposée en 2 phases.

Lors de la première phase, un joueur A appuie sur 4 des 10 boutons qui s’allumeront, présents sur la boîte et fait valider cette combinaison, que l’on va appeler ‘code’, en appuyant sur l’encodeur rotatif.

Lors de la deuxième, un joueur B va tenter une combinaison de 4 boutons qui s’allumeront et la faire valider à l’encodeur rotatif, ainsi l’écran LCD lui répondra le nombre de boutons allumées en accord avec le ‘code’ du joueur A.

Ainsi le joueur B aura x nombre de tentative pour retrouver le ‘code’ qui a été créé par le joueur A.

Je ne vais pas publier de partie code car il n’est pas fonctionnel du tout, je vais prendre de l’avance durant cette semaine car ce mode de jeu risque d’être compliqué à coder, et je souhaiterais qu’il soit fonctionnel pour la Journée Portes Ouvertes de Polytech le samedi 4 février.

Je publierai sûrement un rapport de cette semaine, concernant les modifications de la boîte,sur le code du Mastermind, et peut-être sur le code d’un autre mode de jeu.

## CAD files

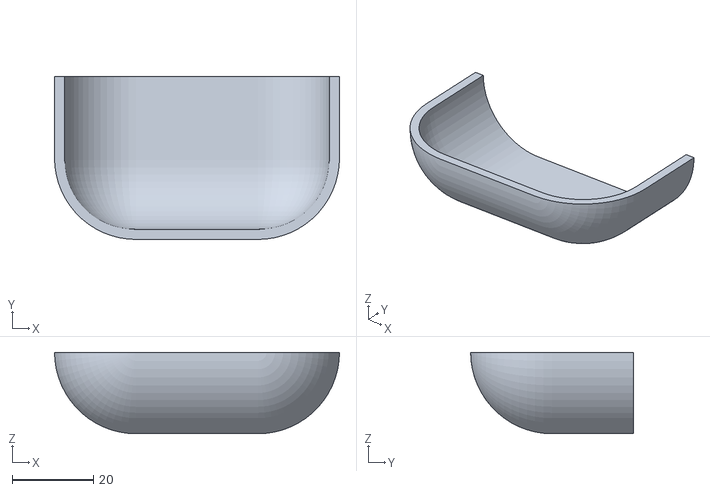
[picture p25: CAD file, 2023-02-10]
Rapports séances/MAUVOISIN Paul/Séance 6/Bac.stl
70.0 x 40.0 x 20.0

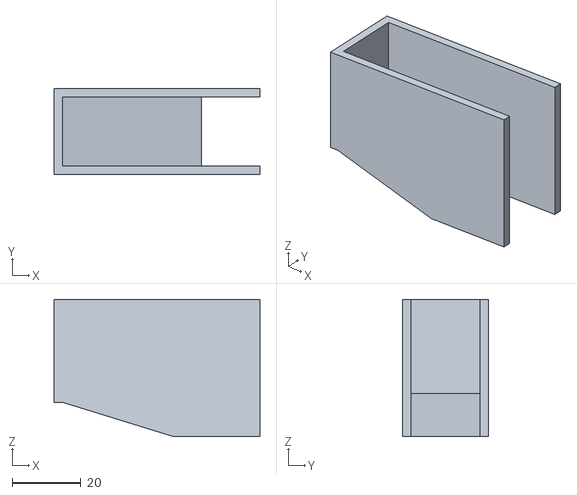
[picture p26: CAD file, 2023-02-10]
Rapports séances/MAUVOISIN Paul/Séance 6/Récipient.stl
60.0 x 25.0 x 40.0

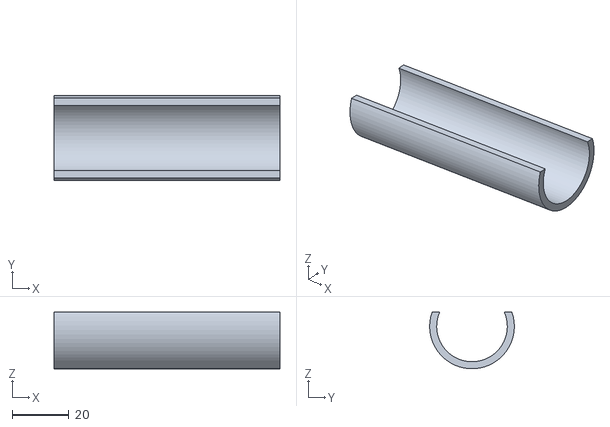
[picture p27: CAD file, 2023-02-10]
Rapports séances/MAUVOISIN Paul/Séance 6/Gouttière.stl
80.0 x 30.0 x 20.0

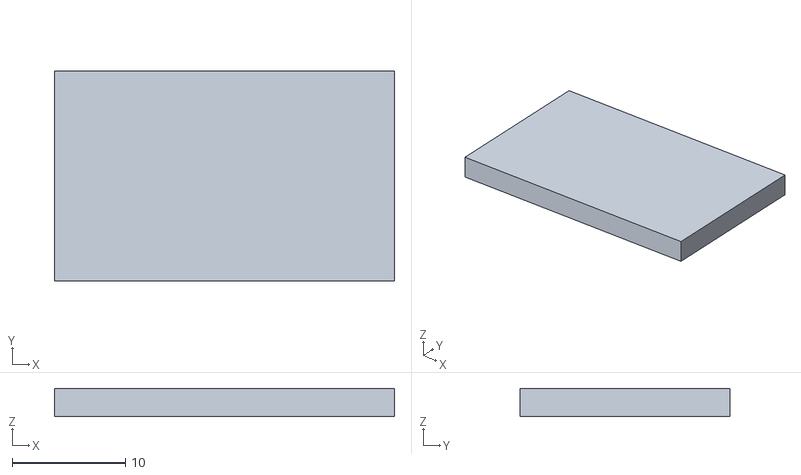
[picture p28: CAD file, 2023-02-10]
Rapports séances/MAUVOISIN Paul/Séance 6/Trap à plat.stl
30.0 x 18.5 x 2.50

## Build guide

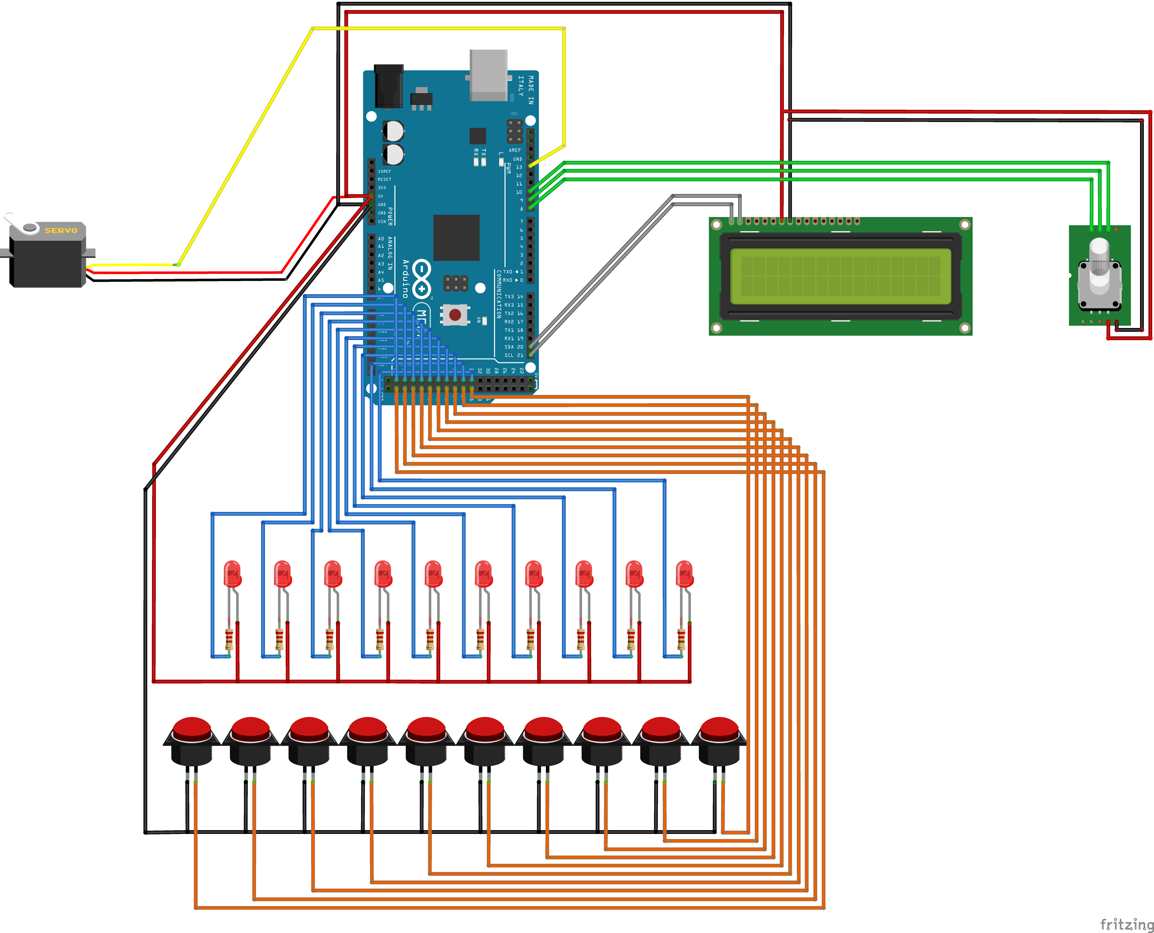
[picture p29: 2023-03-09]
Docs/Fin/Schéma Montage/Polybuzz_bb.png

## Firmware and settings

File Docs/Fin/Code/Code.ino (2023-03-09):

#include <Servo.h>

Servo monservo;  // crée l’objet pour contrôler le servomoteur
#include <Wire.h>
#include <LiquidCrystal_I2C.h>

// include the SD library:
#include <SPI.h>
#include <SD.h>

// set up variables using the SD utility library functions:
Sd2Card card;
SdVolume volume;
SdFile root;

// change this to match your SD shield or module;
// Arduino Ethernet shield: pin 4
// Adafruit SD shields and modules: pin 10
// Sparkfun SD shield: pin 8
// MKRZero SD: SDCARD_SS_PIN
const int chipSelect = 10;

LiquidCrystal_I2C lcd(0x27, 20, 4);

// Bouton
const int bouton_pins[] = {
  53, 51, 49, 47, 45, 43, 41, 39, 37, 35,
};


// LED
const int led_pins[] = {
  52, 50, 48, 46, 44, 42, 40, 38, 36, 34,
};


// Liste bouton taille
const int NOMBRE_BOUTON = sizeof(bouton_pins)/sizeof(bouton_pins[0]); 

// Bouton random
int bouton_aleatoire = 0;
int led_eteinte = 1;

// Temps limite pression bouton (jeu_un)
unsigned long temps_ini = 0;
unsigned long intervalle = 1000;

// Variables pour illuminer les LED (effet visuel)
bool animation_on = true;
int animation_state = 1;
unsigned long animation_temps = 300;
unsigned long animation_temps_ini = 0;


// Simon variables
int temps_simon = 500;
int step = 0;
int num_courant = 0;
int num_courant_joueur = -1;
const int SIMON_LENGTH_MAX = 10;
String etat = "first";
String liste_simon = "";

//Parametres pour l'encodeur rotatif
const int clkPin  = 10;
const int dtPin   = 9;
const int swPin   = 8;

//Variables pour l'encodeur rotatif
int rotVal  = 0;
bool clkState  = LOW;
bool clkLast  = HIGH;
bool swState  = HIGH;
bool swLast   = HIGH;

//Variables pour la fonction: readRotaty
int choix_mode_jeu = 0;
int temps = 0;
int etape = 0;
bool blocage_bouton = HIGH;

//Variables pour la fonction: Timer
int tSec = 15;
int tMin = 1;
unsigned long timeInit=0;
unsigned long intervalleTemps = 1000;
unsigned long previousMillis = 0;
unsigned long currentMillis = 0;

//Variables pour la fonction: Duel
unsigned long temps_duel = 0;
unsigned long intervalle_duel = 1000;
const int INTERVALLE_DUEL_MIN = 1000;
const int INTERVALLE_DUEL_MAX = 10000;
bool duel_led_on = false;
int score_joueur1 = 0;
int score_joueur2 = 0;


//Variables pour la fonction Mastermind

int val[]= {1, 1, 1, 1, 1, 1, 1, 1, 1, 1}; // déclaration d’une variable globale qui mémorise l’état du bouton_pins
int choix_bouton[]={1, 1, 1, 1, 1, 1, 1, 1, 1, 1};
int tentative_bouton[]={1, 1, 1, 1, 1, 1, 1, 1, 1, 1};
int ancien_val[]={1, 1, 1, 1, 1, 1, 1, 1, 1, 1};
int verification_code = 0;
int similitude = 0;
int phase = 1;
int vie = 4;
bool blocage_bouton2 = HIGH;
int isolement_fonction = 0;

// Score
int score = 0;


void write_on_sd_card(String path, String data) {
    File dataFile = SD.open(path, FILE_WRITE);
    if (dataFile) {
        dataFile.println(data);
        dataFile.close();
    }
}

String read_on_sd_card(String path) {
    File dataFile = SD.open(path);
    String data = "";
    if (dataFile) {
        while (dataFile.available()) {
            data += (char) dataFile.read();
        }
        dataFile.close();
    }
    return data;
}

void pinMode_bouton() {
  
  // Initialiser les pins boutons
  for (int i = 0; i < NOMBRE_BOUTON; i++) { 
    pinMode(bouton_pins[i], INPUT_PULLUP);
  }
}

void pinMode_led() {
  
  // Initialiser les pins LED
  for (int i = 0; i < NOMBRE_BOUTON; i++) { 
    pinMode(led_pins[i], OUTPUT);
  }
}

void LED_off() {
  for (int i = 0; i < 10; i++) { 
    digitalWrite(led_pins[i], 1);
  }
}

void setup() {

  Serial.begin(9600);

  pinMode_bouton();
  pinMode_led();
  LED_off();

  // Initialisation de l'afficheur
  lcd.init();
  lcd.backlight();
  setup_afficheur();

  //Initialisation encodeur rotatif
  pinMode(clkPin,INPUT);
  pinMode(dtPin,INPUT);
  pinMode(swPin,INPUT_PULLUP);

  monservo.attach(13);  // utilise la broche 13 pour le contrôle du servomoteur
  monservo.write(180); // trap fermé 
}


void setup_afficheur() {

  lcd.clear();
  lcd.setCursor(3,0);
  lcd.print("Bienvenue");
  lcd.setCursor(2,1);
  lcd.print("Tournez-moi!");

}

void animation_passer_temps() {

    if (millis() - animation_temps_ini > animation_temps) {
            animation_state += 1;
            LED_off();
            animation_temps_ini = millis();
            if (animation_state > 3) {
                animation_state = 1;
            }
    }
}

void animation() {

    if ((animation_state == 1) ) {

        for (int i = 8; i < 10; i++) { 
            digitalWrite(led_pins[i], 0);
        }        
        animation_passer_temps();
    }

    if ((animation_state == 2) ) {

        for (int i = 5; i < 8; i++) { 
            digitalWrite(led_pins[i], 0);
        }        
        animation_passer_temps();
    }

    if ((animation_state == 3)) {

        for (int i = 0; i < 5; i++) { 
            digitalWrite(led_pins[i], 0);
        }       
        animation_passer_temps();
    }

}


void end_game() {

  LED_off();
  lcd.clear();
  lcd.setCursor(0,0);
  lcd.print("Score final:");
  lcd.setCursor(0,1);
  lcd.print(score);
  delay(4000);
  reset_game();

  lcd.clear();
  lcd.setCursor(0, 0);
  lcd.print("Fin de la partie");
  lcd.setCursor(0, 1);
  lcd.print("A bientot, Merci");
  delay(500);
  servo_moteur();
  delay(3000);
  setup_afficheur();

}

void end_game_duel(){

    reset_game();
    lcd.clear();
    lcd.setCursor(0, 0);
    lcd.print("Fin de la partie");
    lcd.setCursor(0, 1);
    lcd.print("A bientot, Merci");
    delay(3000);
    setup_afficheur();

}


void end_game_mastermind() {
  reset_game();
  lcd.clear();
  lcd.setCursor(0, 0);
  lcd.print("Fin de la partie");
  lcd.setCursor(0, 1);
  lcd.print("A bientot, Merci");
  delay(500);
  servo_moteur();
  delay(3000);
  setup_afficheur();
}

void reset_game() {

  //Reset LED
  LED_off();

  // Reset Simon
  temps_simon = 500;
  step = 0;
  num_courant = 0;
  num_courant_joueur = -1;
  etat = "simon";
  liste_simon = "";
  
  // Reset jeu_un
  bouton_aleatoire = 0;
  led_eteinte = 1;
  temps_ini = 0;
  intervalle = 2000;
  
  // Reset Mastermind
  verification_code = 0;
  similitude = 0;
  phase = 1;
  vie = 4;
  blocage_bouton = HIGH;
  isolement_fonction = 0;
  for (int i = 0; i < NOMBRE_BOUTON; i++) {
    val[i] = 1;
    choix_bouton[i] = 1;
    tentative_bouton[i] = 1;
    ancien_val[i] = 1;
  }

    // Reset duel
    temps_duel = 0;
    intervalle_duel = random(INTERVALLE_DUEL_MIN, INTERVALLE_DUEL_MAX);
    duel_led_on = false;
    score_joueur1 = 0;
    score_joueur2 = 0;

  
  // Reset score
  score = 0;

  // Revenir au menu
  etape = 0;

  // Restart animation
  animation_on = true;
}

void jeu_un_next() {
  led_eteinte = 1;
  digitalWrite(bouton_aleatoire - 1, led_eteinte);
  bouton_aleatoire = bouton_pins[random(0,NOMBRE_BOUTON)];
  delay(200);
  temps_ini = millis();
}

void jeu_un() {
  
  if (etat == "first") {
    randomSeed(millis());
    etat = "ok";
  }

  if ((bouton_aleatoire == 0) && (led_eteinte == 1)) {
    bouton_aleatoire = bouton_pins[random(0,NOMBRE_BOUTON)];
  }
  
  if (led_eteinte == 1) {
    led_eteinte = 0;
    digitalWrite(bouton_aleatoire - 1, led_eteinte);
  }
  
  if (led_eteinte == 0) {

    if (((choix_mode_jeu == 1) || (choix_mode_jeu == 2)) && (millis() - temps_ini > intervalle)) {
        jeu_un_next();
    }
    
    for (int i = 0; i < NOMBRE_BOUTON; i++) {

      if (digitalRead(bouton_pins[i]) == 0) {
        if (bouton_pins[i] != bouton_aleatoire) {
          if (score>0) {score -= 1;}
        }
        else {score += 1;}
        jeu_un_next();        
      }
    }  
  }
}


void duel() {

    if (etat == "first") {
        randomSeed(millis());
        etat = "ok";
        intervalle_duel = random(INTERVALLE_DUEL_MIN, INTERVALLE_DUEL_MAX);
        temps_duel = millis();
        lcd.clear();
        lcd.setCursor(0, 0);
        lcd.print("Ready?");
    }

    if ((duel_led_on == false) && (millis() - temps_duel > intervalle_duel)) {
        temps_duel = millis();
        digitalWrite(led_pins[0], 0);
        digitalWrite(led_pins[4], 0);
        intervalle_duel = random(INTERVALLE_DUEL_MIN, INTERVALLE_DUEL_MAX);
        duel_led_on = true;
    }

    if (digitalRead(bouton_pins[0]) == 0) {
        
        if (duel_led_on == true) {
            lcd.clear();
            lcd.setCursor(0, 0);
            lcd.print("Joueur 1");
            lcd.setCursor(0, 1);
            lcd.print("Gagne");
            score_joueur1 += 1;
        }

        else {
            lcd.clear();
            lcd.setCursor(0, 0);
            lcd.print("Joueur 1");
            lcd.setCursor(0, 1);
            lcd.print("Tricheur");
            score_joueur2 += 1;
        }
        duel_led_on = false;
        LED_off();
        delay(1000);
        lcd.clear();
        lcd.setCursor(0, 0);
        lcd.print("Ready?");
    }

    if (digitalRead(bouton_pins[4]) == 0) {
        
        if (duel_led_on == true) {
            lcd.clear();
            lcd.setCursor(0, 0);
            lcd.print("Joueur 2");
            lcd.setCursor(0, 1);
            lcd.print("Gagne");
            score_joueur2 += 1;
        }
        else {
            lcd.clear();
            lcd.setCursor(0, 0);
            lcd.print("Joueur 2");
            lcd.setCursor(0, 1);
            lcd.print("Tricheur");
            score_joueur1 += 1;
        }
        duel_led_on = false;
        LED_off();
        delay(1000);;
        lcd.clear();
        lcd.setCursor(0, 0);
        lcd.print("Ready?");
    }

    if (score_joueur1 > 2) {
        lcd.clear();
        lcd.setCursor(0, 0);
        lcd.print("Victoire du");
        lcd.setCursor(0, 1);
        lcd.print("Joueur 1");
        delay(2000);
        end_game_duel();
    }

    if (score_joueur2 > 2) {
        lcd.clear();
        lcd.setCursor(0, 0);
        lcd.print("Victoire du");
        lcd.setCursor(0, 1);
        lcd.print("Joueur 2");
        delay(2000);
        end_game_duel();
    }

}

void simon() {
    
    if (etat == "first") {
      randomSeed(millis());
      etat = "simon";
    }

    if (etat == "simon") {

      if (step == 0) {
        liste_simon += random(NOMBRE_BOUTON);
      }
      
      for (int i = 0; i < liste_simon.length(); i++) {

        num_courant = liste_simon[i] - '0';
        digitalWrite(led_pins[num_courant], 0);
        delay(temps_simon);
        LED_off();
        delay(temps_simon);
      }

      etat = "joueur";
      step = 0;
    }
    
    
    if (etat == "joueur") {

      for (int i = 0; i < NOMBRE_BOUTON; i++) {
        if (digitalRead(bouton_pins[i]) == 0) {
          num_courant_joueur = i;
          num_courant = liste_simon[step] - '0';
          if (num_courant_joueur == num_courant) {
            step ++;
          }
          else {
            return end_game();
          }
          delay(200);
        }
      }

      if (step >= liste_simon.length()) {
        step = 0;
        etat = "simon";
        score += 1;
      }
    }

    if (liste_simon.length() == SIMON_LENGTH_MAX) {
      return end_game();
    }

}

void afficher_score() {
    lcd.backlight();
    //Envoi du message
    lcd.setCursor(0, 0);
    lcd.print("SCORE: ");
    lcd.setCursor(7, 0);
    lcd.print(score);
}

void loop() {

    //Post gameplay
    readRotary();

    // Animation des leds
    if (animation_on) {
        animation();
    }

  //Etape 4 : le jeu est lancé
  if (etape==4){

    //Jeu 1 (test réflexes)
    if ((choix_mode_jeu == 0) || (choix_mode_jeu == 1) || (choix_mode_jeu == 2)){

      // Réduire le temps durant lequel le bouton est allumé afin d'augmenter la difficulté.
      if (choix_mode_jeu==2) {intervalle = 500;}

      afficher_score();
      jeu_un();
      codeTimer();
    }

    //Simon
    if (choix_mode_jeu==3){ 
      afficher_score();
      simon();
    }
    
    //Mastermind
    if (choix_mode_jeu==4){ 
      mastermind();
    }

    //Duel
    if (choix_mode_jeu==5){ 
      duel();
    }
  }
}

void effet_bouton() {
  for (int i = 0; i < NOMBRE_BOUTON; i++) {
    digitalWrite(bouton_pins[i], 1);
    delay(100);
    digitalWrite(bouton_pins[i], 0);
  }
}

void readRotary( ) {
  //Etape 1 : mode de jeu
  if (etape==0){
    // Gestion position
    clkState = digitalRead(clkPin);
    if ((clkLast == LOW) && (clkState == HIGH)) { //rotary moving
        if (digitalRead(dtPin) == HIGH) {
            rotVal = rotVal - 1;
            if ( rotVal < 0 ) {
                rotVal = 5;
            }
        }
        else {
            rotVal++;
            if ( rotVal > 5 ) {
                rotVal = 0;
            }
        }

        // Selection mode de jeu en tournant l'encodeur rotatif
        if (rotVal==0) {
            lcd.clear();
            lcd.setCursor(0,0);
            lcd.print("Mode de Jeu :");
            lcd.setCursor(0,1);
            lcd.print("Reflexe Easy");
        }
        if (rotVal==1) {
            lcd.clear();
            lcd.setCursor(0,0);
            lcd.print("Mode de Jeu :");
            lcd.setCursor(0,1);
            lcd.print("Reflexe Normal");
        }
        if (rotVal==2) {
            lcd.clear();
            lcd.setCursor(0,0);
            lcd.print("Mode de Jeu :");
            lcd.setCursor(0,1);
            lcd.print("Reflexe Hard");
        }
        if (rotVal==3) {
            lcd.clear();
            lcd.setCursor(0,0);
            lcd.print("Mode de Jeu :");
            lcd.setCursor(0,1);
            lcd.print("Simon");
        }
        if (rotVal==4) {
            lcd.clear();
            lcd.setCursor(0,0);
            lcd.print("Mode de Jeu :");
            lcd.setCursor(0,1);
            lcd.print("Mastermind");
        }
        if (rotVal==5) {
            lcd.clear();
            lcd.setCursor(0,0);
            lcd.print("Mode de Jeu :");
            lcd.setCursor(0,1);
            lcd.print("Duel");
        }
        choix_mode_jeu = rotVal;
        if ((choix_mode_jeu == 3 || choix_mode_jeu == 4 || choix_mode_jeu == 5) && (clkState == LOW)){
          etape = 2;
        }
        delay(200);
    }
  }


  // Etape 2 : reglage du temps
  if (etape==1 && choix_mode_jeu >= 0 && choix_mode_jeu <= 2){  // Le Simon, Mastermind et Duel n'auront pas besoin de temps
    // gestion position
    clkState = digitalRead(clkPin);
    if ((clkLast == LOW) && (clkState == HIGH)) {//rotary moving
        lcd.setCursor(0,0);
        lcd.print("Temps de Jeu :  ");
        if (digitalRead(dtPin) == HIGH) {
            rotVal = rotVal - 1;
            if ( rotVal < 0 ) {
                rotVal = 2;
            }
        }
        else {
            rotVal++;
            if ( rotVal > 2 ) {
                rotVal = 0;
            }
        }

        if (rotVal==0) {
            lcd.setCursor(4,1);
            lcd.print("00:30");
            tSec = 30;
            tMin = 0;
        }
        if (rotVal==1) {
            lcd.setCursor(4,1);
            lcd.print("00:45");
            tSec = 45;
            tMin = 0;
        }
        if (rotVal==2) {
            lcd.setCursor(4,1);
            lcd.print("01:00");
            tSec = 0;
            tMin = 1;
        }
        temps = rotVal;
        timeInit=timeToCounter(tMin,tSec);
        delay(200);
    }
  }


  // Etape 3 : verification, Serial uniquement
  if (etape==2){
    etape = 3;
    blocage_bouton = LOW;
  }


  // Etape 4 : preparation avant lancement
  if (etape==3){
      lcd.clear();
      lcd.setCursor(1,0);
      lcd.print("Lancement dans");
      etape = 4;
      animation_on = false;
      LED_off();
      for(int i=3; i>0; i--){
          lcd.setCursor(7,1);
          lcd.print("0");
          lcd.setCursor(8,1);
          lcd.print(i);
          delay(1000);
    }
     lcd.clear();
     
  }
 
  clickEncodeur();
}

//Partie qui fait fonctionner le "click" de
//l'encodeur rotatif qui fait passer les étapes
void clickEncodeur(){
  clkLast = clkState;
  swState = digitalRead(swPin);
  if (swState == LOW && swLast == HIGH && blocage_bouton==HIGH) {
      lcd.clear();
      lcd.setCursor(0,0);
      lcd.print("Validation etape");
      lcd.setCursor(7,1);
      lcd.print("0");
      lcd.print(etape);
      etape += 1;
      LED_off();
      delay(100);//debounce
  }
  swLast = swState;
}

void mastermind_welcome() {
  blocage_bouton==LOW;
  lcd.setCursor(2,0);
  lcd.print("Choisissez un");
  lcd.setCursor(0,1);
  lcd.print("code a 4 boutons");
  isolement_fonction = 1;
}

void mastermin_phase_une() {
  verification_code = 0;
  for (int i=0; i<10; i++) {
    val[i]=digitalRead(bouton_pins[i]);

    if ((val[i]==LOW)&&(ancien_val[i]==HIGH)) {
      choix_bouton[i]=1-choix_bouton[i];
      delay(200);
    }
    ancien_val[i]=val[i];

    // allume la LED
    if (choix_bouton[i]==LOW) { 
      digitalWrite(led_pins[i], LOW);
    }

    // éteint la LED
    if (choix_bouton[i]==HIGH) { 
      digitalWrite(led_pins[i], HIGH);
    }

    if (digitalRead(led_pins[i])==LOW){
      verification_code += 1;
    }
  }

  if (swState == LOW && verification_code == 4){
    phase = 2;
    for (int i=0; i<10; i++) {
      digitalWrite(led_pins[i], HIGH);
      val[i] = 1;
      ancien_val[i] = 1;
    }
    lcd.clear();
    lcd.setCursor(2,0);
    lcd.print("Code valide");
    delay(3000);
    lcd.clear();
    lcd.setCursor(3,0);
    lcd.print("Trouvez le");
    lcd.setCursor(0,1);
    lcd.print("code a 4 boutons");
  }
}

void mastermin_phase_deux() {
  verification_code = 0;
  for (int i=0; i<10; i++) {
    val[i]=digitalRead(bouton_pins[i]); // lecture de l’état de l’entrée 2

    if ((val[i]==LOW)&&(ancien_val[i]==HIGH)) {
      tentative_bouton[i]=1-tentative_bouton[i];
      delay(200);
    }
    ancien_val[i]=val[i];

    if (tentative_bouton[i]==LOW) { // allume la LED
      digitalWrite(led_pins[i], LOW);
    }
    if (tentative_bouton[i]==HIGH) { // éteint la LED
      digitalWrite(led_pins[i], HIGH);
    }

    if (digitalRead(led_pins[i])==LOW){
      verification_code += 1;
    }
  }

  similitude = 0;
  if (swState == LOW && verification_code == 4 && blocage_bouton2 == HIGH){
    blocage_bouton2 = LOW;
    lcd.clear();
    lcd.setCursor(0,0);
    lcd.print("Similitude: ");
    lcd.setCursor(0,1);
    lcd.print("Vie restante:");
    for (int i=0; i<10; i++) {
      if (choix_bouton[i] == 0 && tentative_bouton[i] == 0){
        similitude += 1;
      }
      if (similitude == 4){
        phase = 3;
        lcd.clear();
      }
      if (vie == 1){
        phase = 4;
        lcd.clear();
      }
    }
    vie -= 1;
    lcd.setCursor(14,0);
    lcd.print(similitude);
    lcd.setCursor(14,1);
    lcd.print(vie);
  }

  if (swState == HIGH){
    blocage_bouton2 = HIGH;
  }
}

void mastermind_phase_trois() {
  lcd.setCursor(2,0);
  lcd.print("Victoire du  ");
  lcd.setCursor(3,1);
  lcd.print("Decrypteur  ");;
}

void mastermin_phase_quatre() {
  lcd.setCursor(2,0);
  lcd.print("Victoire du  ");
  lcd.setCursor(4,1);
  lcd.print("Crypteur    ");
}

void mastermind() {

  if (isolement_fonction==0){
    mastermind_welcome();
  }

  else {

    // Etape 1 : Choix du code
    if (phase == 1){mastermin_phase_une();
    }

    // Etape 2 : Tentative de trouver le code
    if (phase == 2){
      mastermin_phase_deux();
    }

    // Etape 3 ou 4 : fin
    if ((phase == 3) || (phase == 4)) {
      if (phase == 3) {
        mastermind_phase_trois();
      }
      else {
        mastermin_phase_quatre();
      }
      delay(5000);
      return end_game_mastermind();
    }
  }
}

void codeTimer(){
  //Envoie du temps choisit par le joueur
  //à la fonction qui calcule
  counterToTime(timeInit);

  //Affichage Timer normal
  if(timeInit != 0){
    //Affichage de base
    lcd.setCursor(0,1);
    lcd.print("Temps: ");
    lcd.setCursor(8,1);
    lcd.print(":");

    //Affichage min
    lcd.setCursor(7, 1);
    lcd.print(tMin);

    //Affichage sec, problème de décalage des sec inférieures à 10
    if (tSec > 9){
      lcd.setCursor(9, 1); 
      lcd.print(tSec);
    }

    else{
      lcd.setCursor(9, 1); 
      lcd.print(0);
      lcd.setCursor(10, 1);
      lcd.print(tSec);
    }

    //Faire passer 1sec
    currentMillis = millis();
    if (currentMillis - previousMillis > intervalleTemps){
      previousMillis = currentMillis;
      timeInit = timeInit-1;
    }
   }

   //Timer arrivé à la fin
   if (timeInit==0) {
    end_game();
   }
}

//Conversion en sec du Timer
int timeToCounter(int m,int s){
  return m*60+s;
}

//Fonction de calcule du temps choisit
void counterToTime(long cnt){
  tMin = (cnt%3600)/60;
  tSec = ((cnt%3600)%60);
}

//Fonction pour les récompenses (activation servomoteur)
void servo_moteur(){
  monservo.write(120);
  delay(500);
  monservo.write(180);
}

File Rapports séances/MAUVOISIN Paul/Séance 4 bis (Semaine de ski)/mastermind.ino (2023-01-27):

#include <Wire.h>
#include <LiquidCrystal_I2C.h>

LiquidCrystal_I2C lcd(0x27, 20, 4);

//LED qui s’allume quand on appuie sur un bouton
const int led[]={5, 6, 7, 12}; //on définit une constante de type entier
const int bouton[]={8, 9, 10, 13}; //on définit une autre constante de type entier

int val[]={1, 1, 1, 1}; // déclaration d’une variable globale qui mémorise l’état du bouton
int choix_bouton[]={1, 1, 1, 1};
int tentative_bouton[]={1, 1, 1, 1};
int ancien_val[]={1, 1, 1, 1};
int verification_code = 0;
int similitude = 0;
int etape = 1;
int vie = 4;
bool blocage_bouton = HIGH;


//Parameters
const int clkPin  = 2;
const int dtPin  = 3;
const int swPin  = 11;

//Variables
int rotVal  = 0;
bool clkState  = LOW;
bool clkLast  = HIGH;
bool swState  = HIGH;
bool swLast  = HIGH;


void setup(){
  Serial.begin(9600);
  Serial.println("Initialisé");
  for (int i=0; i<4; i++) {
    pinMode(led[i], OUTPUT); // l'I/O 2 est utilisée comme une sortie
    pinMode(bouton[i], INPUT_PULLUP); // l'I/O 7 est utilisée comme une sortie
  }

  //Init Rotary
  pinMode(clkPin,INPUT);
  pinMode(dtPin,INPUT);
  pinMode(swPin,INPUT_PULLUP);

  lcd.init();
  lcd.backlight();
  lcd.setCursor(2,0);
  lcd.print("Choissiez un");
  lcd.setCursor(0,1);
  lcd.print("code a 4 boutons");
}


void loop() {
  mastermind();
  clickEncodeur();
}

void mastermind(){
  // Etape 1 : Choix du code
  if (etape == 1){
    verification_code = 0;
    for (int i=0; i<4; i++) {
      val[i]=digitalRead(bouton[i]); // lecture de l’état de l’entrée 2
  
      if ((val[i]==LOW)&&(ancien_val[i]==HIGH)) {
        choix_bouton[i]=1-choix_bouton[i];
      }
      ancien_val[i]=val[i];
  
      if (choix_bouton[i]==LOW) { // allume la LED
        digitalWrite(led[i], LOW);
      }
      if (choix_bouton[i]==HIGH) { // éteint la LED
        digitalWrite(led[i], HIGH);
      }

      if (digitalRead(led[i])==LOW){
        verification_code += 1;
      }
    }
  
    if (swState == LOW && verification_code == 2){
      etape = 2;
      for (int i=0; i<4; i++) {
        digitalWrite(led[i], HIGH);
        val[i] = 1;
        ancien_val[i] = 1;
      }
      Serial.println("Validé");
      Serial.println("Passage à l'étape 2");
      lcd.clear();
      lcd.setCursor(2,0);
      lcd.print("Code valide");
      delay(3000);
      lcd.clear();
      lcd.setCursor(3,0);
      lcd.print("Trouvez le");
      lcd.setCursor(0,1);
      lcd.print("code a 4 boutons");
    }
  }

  // Etape 2 : Tentative de trouver le code
  if (etape == 2){
    verification_code = 0;
    for (int i=0; i<4; i++) {
      val[i]=digitalRead(bouton[i]); // lecture de l’état de l’entrée 2
  
      if ((val[i]==LOW)&&(ancien_val[i]==HIGH)) {
        tentative_bouton[i]=1-tentative_bouton[i];
      }
      ancien_val[i]=val[i];
  
      if (tentative_bouton[i]==LOW) { // allume la LED
        digitalWrite(led[i], LOW);
      }
      if (tentative_bouton[i]==HIGH) { // éteint la LED
        digitalWrite(led[i], HIGH);
      }

      if (digitalRead(led[i])==LOW){
        verification_code += 1;
      }
    }

    similitude = 0;
    if (swState == LOW && verification_code == 2 && blocage_bouton == HIGH){
      blocage_bouton = LOW;
      lcd.clear();
      lcd.setCursor(0,0);
      lcd.print("Similitude: ");
      lcd.setCursor(0,1);
      lcd.print("Vie restante:");
      Serial.println("Check en cours");
      for (int i=0; i<4; i++) {
        Serial.print(choix_bouton[i]);
        Serial.print(" = ");
        Serial.println(tentative_bouton[i]);
        if (choix_bouton[i] == 0 && tentative_bouton[i] == 0){
          similitude += 1;
        }
        if (similitude == 2){
          Serial.println("vrai");
          etape = 3;
          lcd.clear();
        }
        if (similitude != 2){
          Serial.print("faux, il y a ");
          Serial.print(similitude);
          Serial.println(" similitude");
        }
        if (vie == 0){
          etape = 4;
          lcd.clear();
        }
      }
      vie -= 1;
      Serial.print("vie restante");
      Serial.println(vie);
      lcd.setCursor(14,0);
      lcd.print(similitude);
      lcd.setCursor(14,1);
      lcd.print(vie);
    }

    if (swState == HIGH){
      blocage_bouton = HIGH;
    }
  }

  // Etape 3 : fin gagné
  if (etape == 3) {
    Serial.println("Bravo");
    lcd.setCursor(2,0);
    lcd.print("Victoire du  ");
    lcd.setCursor(3,1);
    lcd.print("Decrypteur  ");
  }

  // Etape 4 : fin perdu
  if (etape == 4) {
    Serial.println("Perdu");
    lcd.setCursor(2,0);
    lcd.print("Victoire du  ");
    lcd.setCursor(4,1);
    lcd.print("Crypteur    ");
  }
}

void clickEncodeur(){
  //gestion bouton
  swState = digitalRead(swPin);
  if (swState == LOW && swLast == HIGH) {
    Serial.println("Rotary pressed");
    delay(100);//debounce
  }
  swLast = swState;
}

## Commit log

2022-12-16 Create Code Timer
2023-01-14 Error 404: Brain Not Found
    [Polybuzz.fzz]
2023-02-03 remove serial.print
